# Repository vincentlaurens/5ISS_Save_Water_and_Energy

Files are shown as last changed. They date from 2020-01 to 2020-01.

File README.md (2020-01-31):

# Sensibilisation tool to save water and energy

Written by ILYA team

# Table of Contents
1. [Introduction](#introduction)
2. [TreeMap of the repository](#paragraph1)
3. [Architecture of the solution](#paragraph2)
4. [Device Layer](#paragraph3)
5. [Network Layer](#paragraph4)
6. [Application Layer](#paragraph5)
7. [VM](#paragraph7)
8. [Deployment](#paragraph8)

## Introduction 

Nowadays, people are becoming increasingly concerned about the future of our planet. The consequences of climate change are worse every year. Fighting against it has become a source of inspiration for many young entrepreneurs. ILYA is a young startup that is developing two products: a cyclic shower to reduce water consumption and an awareness tool to sensitive people to save water, energy and therefore money when taking a shower. In this report, we present in detail the second product, a tool that allows measuring in real-time the water and energy consumption during a shower. The prototype we developed consists of a sensor system that collects data on the water flow and quantity, stores it in a database, and then display an analysis of this data on a web interface.  The data is captured by an autonomous and energy-efficient node and is then sent via WiFi to a local server to be stored in a database and then on the cloud. The final prototype is not fully optimized but both simple and realistic.

## TreeMap of the repository 
```
Project ILYA
    |-README
    |-Documentation
    |   |-rapport.pdf
    |   |-Presentation.pdf
    |-DeviceLayer
    |   |-ESP_Code
    |-ApplicationLayer
    |   |-data_structure_api
    |   |-UI
    |-VM
    |   |-README
```

## Architecture of the solution 

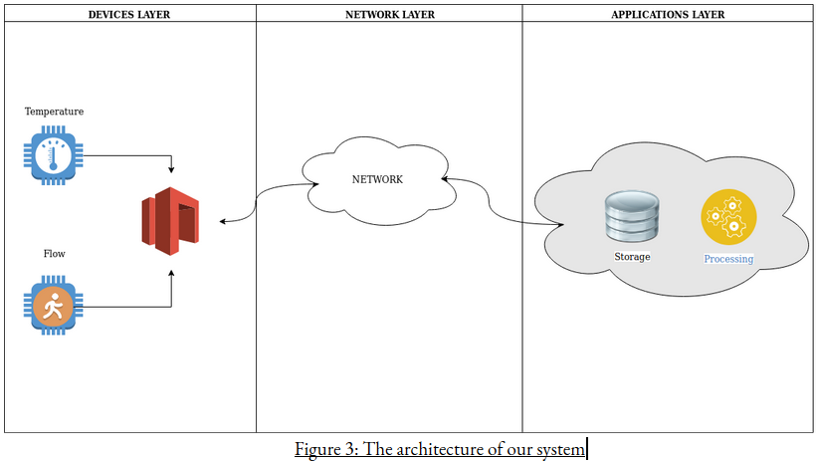
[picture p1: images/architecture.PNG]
Architecture


## Device Layer 

The Device layer is Composed of 4 different components for one module.
There are 2 sensors , 1 Microcontroller, 1 Shield.
This is the Bom of our Module:

|DEVICE NAME	 |Quantity |
| ---: | ---: |
|Grove - Temperature Sensor V1.2 | x1 |
|YFS-201 Hall Effect Water Flow Sensor | x1 |
|Node-MCU ESP8266	X1 | x1 |
|Grove Base Shield for NodeMCU | x1 |

The Arduino Code can retrieve data from sensors during a certain period : each 10 sec
Number of acquisition : 7 , Total time of acquisition : 70 sec.

This parameters are configurable in the source code which is commented to know the purposes of functions and variables
<a href="https://drive.google.com/file/d/1UWVMobrCpHeJf4AdiO7gw0xYP0oA8SGS/view?usp=sharing">Bill of Material (document)</a>

## Network Layer 

1.  Create an account on http://maqiatto.com
   Click on "CREATE ACCOUNT"
   Create your account
2.  After login, clic on your email address on the left top corner
   On the dropdown menu clic on "Broker configuration"
3.  Next page should appear
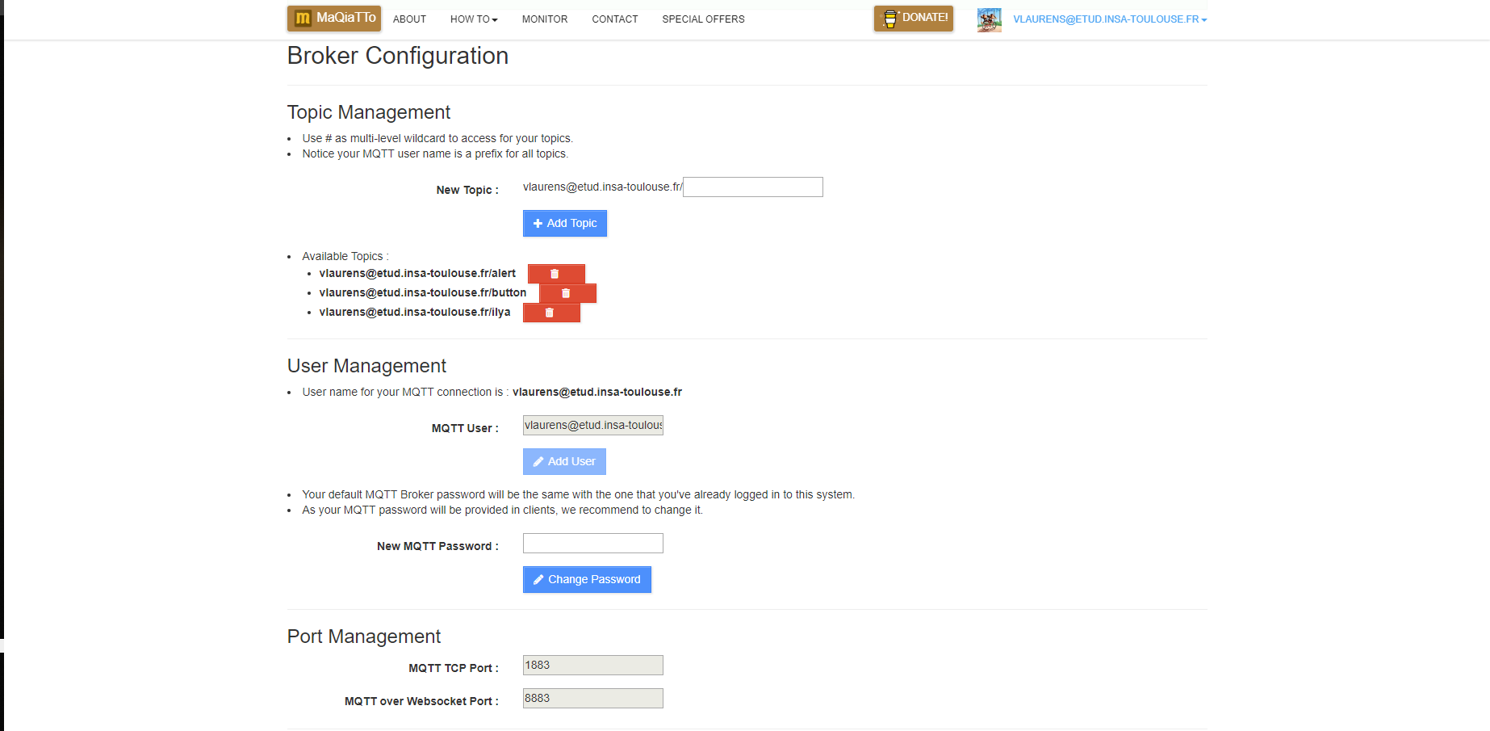
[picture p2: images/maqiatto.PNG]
Maqiatto broker configuration
    
    ADD the same topics as shown on the figure (cf First part :Device Layer where you have to replace created topic on the  global code variables)
4. Once differents topics are created you can monitor reception of JSON object by connecting to the http://www.hivemq.com/demos/websocket-client/ on a private window in your browser.
    Then you have to fill all the fields as shown in the next figure
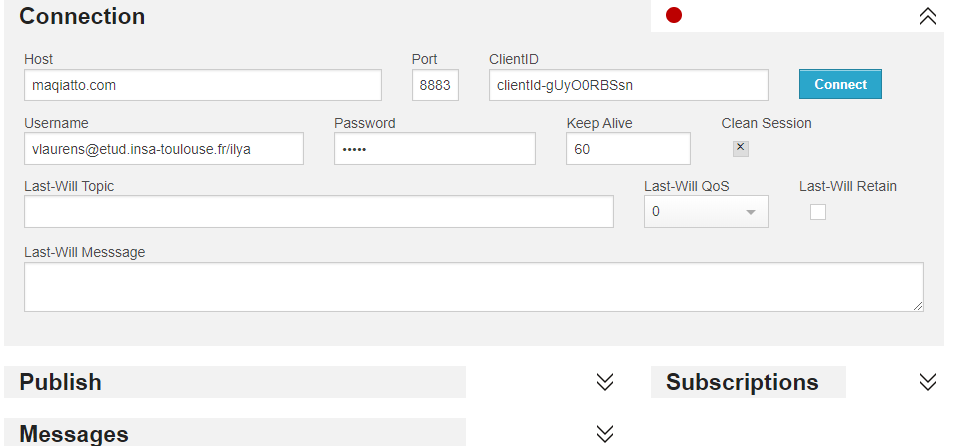
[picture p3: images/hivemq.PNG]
hivemq configuration
    
    Note that vlaurens@etud.insa-toulouse.fr/ilya is the main topic where all data are going to be sent. ( <maqiattoUsername>/ilya ingeneral).
 Ajouter image après  connexion

## Application Layer 

You can deploy the application either on a Ubuntu Virtual Machine or by deploying containers as describe in part 7 or on your computer if you have python installed but you will need to install some python modules using command and install mongo (https://docs.mongodb.com/manual/installation/) and for configuring data base mongodb-compass (https://www.mongodb.com/products/compass)
````
$  sudo apt-get update && apt-get install -y apt-utils && apt-get install -y python && apt-get install -y python-pip && pip install requests && pip install flask && pip install flask_restplus && pip install paho-mqtt && pip install pymongo
````
Then if you decide to install on your machine you have to install npm and nodejs (https://nodejs.org/fr/download/) to be able to install node-red and run the UI.

Then you will download the "ApplicationLayer/data_structure_api" folder from git repository

Move on the folder and run command:
````
$ python app.py
````

The API is ready to collect data from broker and store it on mongodb.

Then run 
````
$ node-red
````
Then open a browser and go on http://127.0.0.1:1880

If you can't show flows import the two flows which are on folder "ApplictionLayer/UI" as described on the following tutorial: https://nodered.org/docs/user-guide/editor/workspace/import-export.

  If some package are missing install "node-red-contrib-ui" via install menu of nodered.
  
    - Go on the same menu as import 
    - Choose "manage Palette"
    - Go on install package section
    - Search "node-red-contrib-ui" and install it
    - Exit and close "manage Palette" popup
    - Then Deploy Flow by clicking on "Deploy" Button.
    - Visit http://127.0.0.1:1880/ui
    
Then we present you a means to install a VM or the VM we prepare and do the same operation to deploy application on the VM.

We finally show how to deploy our application with containers docker instead of using VM. A better solution for a large scale deployment.

Notice : The VM can be deploy directly on a cloud platform.

## VM 
- Download the VM on the link : https://drive.google.com/drive/folders/14bD5Wj_I1dPEdrXSYJpSs-G7y7vcGLyr?usp=sharing
- Install VirtualBox and launch the VM. You can do like in this tutorial :<a href="https://www.vulgarisation-informatique.com/installer-virtualbox.php"> How to install VirtualBox and launch VM</a>
- Connect to the VM using  ilya/ilya then you have a document which explains every thing on the VM Desktop.
- Go on API folder
```bash 
  $ cd ~/Documents/API/data_structure_api/
  ```
 - Run the API like describe on Application Layer section:
 ````
$ python app.py
````
- Open a browser and enter http://127.0.0.1:1880/ui to show dashboards.
- If you can't access it:
- Run on a Terminal (ctrl+Alt+T) : node-red  command
 ```bash 
  $ node-red
  ```
- Then go on http://127.0.0.1:1880 you will see code of flows and then you can modify them or deploy them.
  You will find flows on 
  ```bash 
  $ cd ~/Documents/API/UI/
  ```
  If you can't show them import the two flows which are on folder "ApplictionLayer/UI" as described on the following tutorial: https://nodered.org/docs/user-guide/editor/workspace/import-export.
  If some package are missing install "node-red-contrib-ui" via install menu of nodered.
  
    - Go on the same menu as import 
    - Choose "manage Palette"
    - Go on install package section
    - Search "node-red-contrib-ui" and install it
    - Exit and close "manage Palette" popup
    - Then Deploy Flow by clicking on "Deploy" Button.
    - Visit http://127.0.0.1:1880/ui
  
  If you want to monitor DataBase you can open a terminal (you can use shortcut ctrl+Alt+T) enter the command : "mongodb-compass&"
  
- Then open a browser and see the interface. enter 127.0.0.1:27017 and press enter.
  You will see all the databases. The databases are created by the API at the first data reception.
  
  <a src="./VM/README.md">VM Documentation</a>
  
## How to deploy our services on cloud by barely method or using a host OS 

In folder "services" run following command to deploy services
```bash
$ docker-compose up -d
```
run following command to stop all services
```bash
$ docker-compose down
```

Then open 127.0.0.1:1880 and on the interface
select menu on the top-right corner
In the menu select "manage palette" and in install menu
Install node-red-dashboards

Then select import menu and import two json file which are located in folder ilyaUI directory

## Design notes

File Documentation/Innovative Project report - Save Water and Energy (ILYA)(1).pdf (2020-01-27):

## Innovative Project report

# Save Water and Energy

## Consumption awareness tool

INSA students

Karim Aldandachi
Mickaël Commerot
Vincent Laurens
Lorine Pose
Hamza Safri

ILYA founders

Simon Buoro
Antoine Escande

INSA Tutor

Thierry Monteil

## Acknowledgments

We would like to thank first of all Simon Buero and Antoine Estande, ILYA’s co-founders, for trusting us with their project and for giving us the opportunity to work on it.

We would like to also express our gratitude to our INSA tutor, Thierry Monteil, who accompanied us during this project, and we thank him for all the advice and help he provided us with.

We really appreciate the help given to us by Gauchard David, mainly on the ESP8266 development. His contribution was essential to the completion of this project.

Finally, we would like to thank our English teacher, Joseph Shea, for helping us with our written reports and oral presentations, and for always making sure our English is correct.

We dedicate the result of our hard work to our beloved classmate, Lorine Pose, who we know did the best she could to be a part of this project. We send her our best wishes.

2

## Abstract

Nowadays, people are becoming increasingly concerned about the future of our planet. The consequences of climate change are worse every year. Fighting against it has become a source of inspiration for many young entrepreneurs. ILYA isa young startup that is developing two products:a cyclic shower to reduce water consumption and an awareness tool to sensitive people to save water, energy and therefore money when taking a shower. In this report, we present in detail the second product, a tool that allows measuring in real-time the waterand energy consumption during ashower. The prototype we developed consists of a sensor system that collects data on the water flow and quantity, stores it in a database,and then display an analysis of this data on a web interface. The datais captured by an autonomous and energy-efficient node and is then sent via WiFi to alocal server to be stored in a database and then on the cloud. The final prototype is not fully optimized but both simple and realistic.

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
## I. Introduction

ILYA is a french start-up that aims to decrease the environmental impact of everyday actions by offering innovative and durable solutions to assist companies in their responsible approaches. Their first project is a sensibilization tool that provides an energy and water consumption diagnostic service to its clients.

Today, particularly in hotels, people tend to have an irresponsible consumption of water and energy. This phenomenon is mostly due to the fact that since they paid for the room, they feel the need to make the stay as profitable as possible.

To tackle this issue, ILYA wants to develop a solution that sensitizes people about their water and energy consumption in order to decrease it. This tool will be installed first in public places like hotels and camps, measuring the consumption, analyzing the collected data and then displaying it on a screen. Therefore, the person will be able to know how much he or she is consuming, while in the shower!

## II. State of Art

Before starting to design the prototype, we needed to research the tools and technologies we were going to use, mainly the circuit board and the type of database. Below is the result of our research.

A. Hardware

Before we started to design our prototype, we wrote down a list of requirements that the prototype had to respect. For example, it has to be autonomous and self-dependant on energy. In fact, the client will add that module in a bathroom and the system must beable to stand-alone foras long as possible. Therefore, we needed a module that is able to fetch data from sensors and to send them to a cloud using a Wi-Fi protocol, all while consuming the least amount of energy possible.

We chose to use ESP boards rather than other constructor boards like STM because we wanted a board that can connect to WiFi. Furthermore, the development kit proposed by ESP relies on Arduino’s development IDE (https://www.arduino.cc/en/Main/Software) , which is very easy to use. More importantly, ESP cards and Arduino
1
IDE had already been used by all team members in previous projects. For example, most team members used the ESP8266 board during INSA’s Hackathon back in December of last year.

1 https://www.arduino.cc/en/Main/Software

5

We narrowed the choices down to two ESP boards: ESP8266 and ESP32. The following paragraph will describe studies on the energy consumption of those two modules. In the first part, we will compare the energy consumption of ESP8266 and ESP32. In the second part, we will present the development environments used to develop the software of these boards.

To measure the energy consumption of both boards, we used a USB Safety Tester, which is a basic plug-in USB tester that displays voltage and current values.

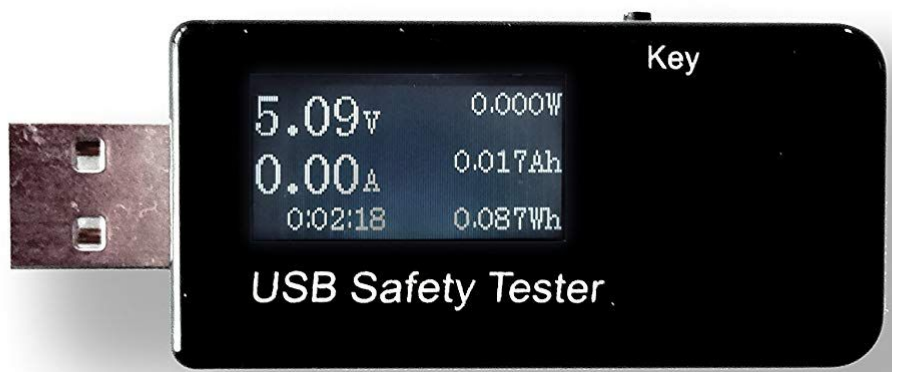
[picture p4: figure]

Figure 1: The USB Safety Tester

Below is a table presenting in more detail the different characteristics of each board.

| ESP32 | ESP8266
Microprocessor | Xtensa Dual-Core 32-bit LX6 with 600 DMIPS | Xtensa Single-core 32-bit L106
Number of cores | 2 | 1
Wi-Fi | Yes | Yes
Bluetooth | Yes | No
Supply needed in Run mode | 110 mA | 80 mA
Supply needed in Sleep mode | 50 mA | 20 mA
Energy consumption per min (I/P=UI/E=PI) Accuracy 1A | 110mA/0.05Watts/33 Joules | 80mA/0,04 Watts/24 Joules
Energy Management integrated | Yes | No

Table 1: Comparison between ESP32 and ESP8266 board

The results above show that an ESP8266 board consumes less energy than an ESP32 board with the same test conditions (program, temperature, sensors connected…). But if we look at the performance

6

aspect, an ESP32 board with two cores is more efficient than an ESP8266, which uses one core for Wi-Fi connection and transmission, and the other one to process data collection from sensors.

The development environment is something that must be taken into consideration because it is used to design the “brain” of the board. One thing that is important to mention is thatan ESP board hasa RISC microcontroller, which means that it can be programmed in C++ using Arduino IDE. This criterion is another reason, after the ability to connect to Wi-Fi, that comforted our choice ofan ESP board rather than an STM board.

In the end, we chose ESP8266. In fact, our system doesn’t necessarily need a high performing board because it will only collect and send data via Wi-Fi. The energy consumption criteria was a more critical point for our choice.

Complementary to the hardware part, we know that traditional groovesare very big so we had to think of a way to reduce the size, by having fewer inputs for example. We designed a PCB groove shield that is the size of the circuit board. It can be found in theappendix at the end of this document (Appendix 3).

B. Database

For our database, we had two options, SQL and NoSQL, the most common types of databases. We decided to compare them based on attributes like consistency, availability,and speed and then choose depending on the needs of our application.

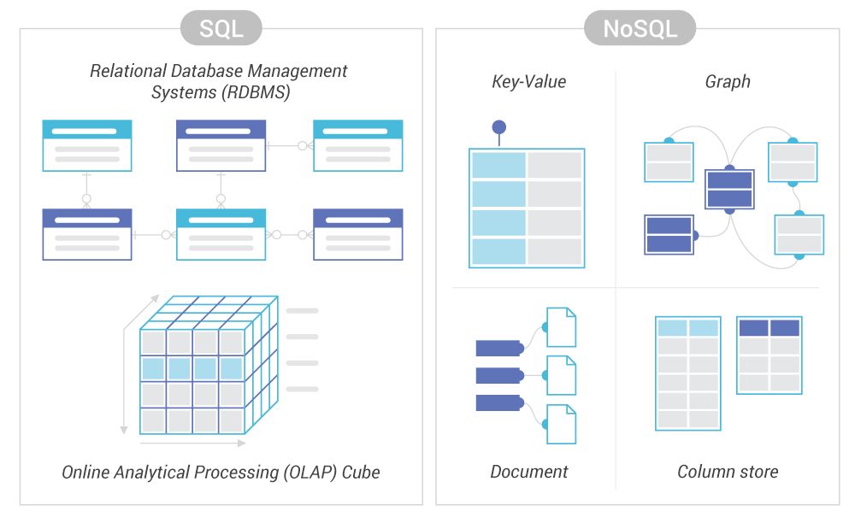
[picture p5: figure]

Figure 2: A representation of SQL and NoSQL databases

7

Source: https://www.scylladb.com/resources/nosql-vs-sql/

SQL stands for Structured Query Languageand is the traditionaland most popular database system. It is based on the relational model, which means that data is stored in interrelated tables, with rowsand columns. An indexing mechanism supported by SQL is used to speed up various operations like reading or creating views, which can join data from multiple tables. Examples of relational databases available are MySQL, Oracle, and SQLServer.

However, in the last couple of years, another database system has grown in popularity, due to its ease of access, speed, high scalability, and distributed computing. NoSQL is a non-relational database management system that supports flexible schema to store the data. NoSQL databases supportalarge scale of data storing by providing distributed data stores. Most of them are based on storing key-value pairs. Hence, they are suitable to store data generated by IoT applications. An example of a NoSQL database is MongoDB.

| SQL | NoSQL
Model | Relational database system | Non-relational database system
Data storage | Tables (rows and columns) | Documents, column stores, graphs, key-value pairs
Schema | Fixed, very hard to modify | Schema-free database, easy to modify
Data structure | Structured data | Semi-structured or unstructured data
New fields | Adding new fields in the table may require altering the schema | New fields can be added with much more ease
Scalability | Scales well vertically | More suited for horizontal scaling
Querying language | Use of powerful declarative language | Use of JSON data objects
Transactions | Supports ACID transactions | ACID transactions support varies per solution
Consistency | Strong | Eventual

8

Table 2: Comparison between SQL and NoSQL databases The following paragraphs are based on the paper written by Rautmare, S. and Bhalerao, D.

- Data model:
SQL is a relational database where data is stored in the form of rows and columns in tables that are linked together. In the table, columns represent different fields, while rows represent the records. This data model gives a well organized but rigid structure of data. For example, the same table cannot be used to store different kinds of information. You also can’t inserta number whereastring is expected. This strict data template enables a low probability of a user making mistakes.

On the other hand, NoSQL is a non-relational database that uses data modeling types like document stores, key-values, and graphs. Similar documents can be stored in a collection, which is analogous to an SQL table. You can store any type of datain any document. This flexibility can lead to consistency issues. Nonetheless, this feature proves to be efficient when handling unstructured data like Word, PDF or multimedia files.

In IoT applications where data structure cannot be predefined properly or data is heterogeneous, NoSQL definitely has a higher edge. But for simplerapplications,afixed datastructure is enough and accessing data is faster.

- Scalability:
Vertical scalability is the ability to scale up or to add resources to a single node in a system, typically involving the addition of CPUs or memories to a single computer. Traditional databases like SQL were designed primarily to scale vertically by adding more power to a single node. Horizontal scalability is the ability to scale out or to add more nodes (servers) to the system so its load can be shared. It is one of the main characteristics of NoSQL.

For IoT applications where the distribution of data amongst several servers is required, the use of NoSQL isa better option because itallows the expansion of the hardware system in astepwise manner, without needing to invest in high-end modules of hardware.

- Data Retrieval:
To look up data in SQL databases, the user needs to collect it from interlinked tables using JOIN statements and then combine the results. The process is the same when writing.

In NoSQL, each piece of data represents an object which contains all its related data. This allows a much faster Read and Write operations. This feature is mainly required when analyzing the datastored in the database or when taking any action on a specific record.

9

- Transactions:
Relational databases like SQL support ACID (Atomicity, Consistency, Isolation, Durability) properties and hence guarantee the validity of all transactions. NoSQL supports BASE (Basically Available, Soft state, Eventual consistency) properties, focusing more on eventual consistency, providing availability and on being partition tolerant.

For IoT applications in their developing stage, data generation increases day by day. So, a database system that is partition tolerant is more suitable. Also, in IoT applications where datais collected first and then analyzed, later on, the database can be eventually consistent. In this case, strong consistency is not a mandatory characteristic. It is better suited in application scenarios where an immediate update of data is necessary (online reservation systems, inventory systems, retail stores, banking).

- Maturity of the system:
Finally, one of the most important issues in a database is security. As NoSQL is a recent technology and hence is less mature, it is more likely to generate new issues, due to alack of knowledge. Developers have less experience with newer database systems, so mistakes are made. On the other hand, in SQL, most of the issues are all addressed as it has been used for several years now. Security concerns like authentication, data integrity, confidentiality, auditing, and client communication are addressed in SQL. In NoSQL, they are yet to be integrated.

In the IoT ecosystem, sensors transfer a lot of sensitive information. So, it is necessary to haveasecure channel for information exchange and a secure system to store this sensitive data. For applications where data security and integrity is of high priority, it is better to go for a secured data storage like SQL.

After studying all these different attributes, we opted for a NoSQL database because its structure is more suited to the evolving data schemas of our project.

## III. The implementation

a) A general overview of the tool

The tool consists of sensors, a circuit board, and a cloud. The sensors are placed on the showerhead and measure the temperature as well as the water flow. The circuit board then receives the data and sends it to the cloud, where a database is stored.

Each sensor is linked to a specific hotel room when configured. In fact, we need to beable to attribute each data to the corresponding shower head.

10 b) The architecture of the tool

To design our tool’s architecture, we got the inspiration from the M2M standard developed by the European Telecommunication Standard Institute (ETSI), which is used in many markets, such as Connected Vehicles, Smart Metering, and e-Health.

ETSI identifies three domains: Application, Network, and Device. The Device layer consists of sensors, actuators, and any other type of device found in a wireless sensor network. It also contains a gateway to be used by devices that can’t connect by themselves to the M2M core. The Application layer, as its name suggests, contains all the differentapplications. Finally, the Network layer providesa communication network between the Application and the Device domains. [1]

For our specific tool, here is how we designed the architecture:

- The device layer contains the different sensors (flow and temperature) which are connected to an ESP8266 circuit board. These sensors send the collected data using the Wi-Fi module of the board to a broker, which in turn sends them to M2M applications.
- The network layer is responsible for the communication between the circuit board and the database. This is done thanks to a broker. A broker is something or someone that acts as an intermediary third party, managing transactions between two other entities. In the case of our tool, the broker is an intermediary computer program module that publishesa message forall subscribed applications.
- The application layer provides 2 services. The first consists of a MongoDB database that receives and stores the collected data. The second isan interface used by the supplier (Ilya)and the clients (hotel managers) to configure sensorsand visualize the collected datain the form of graphs.

11

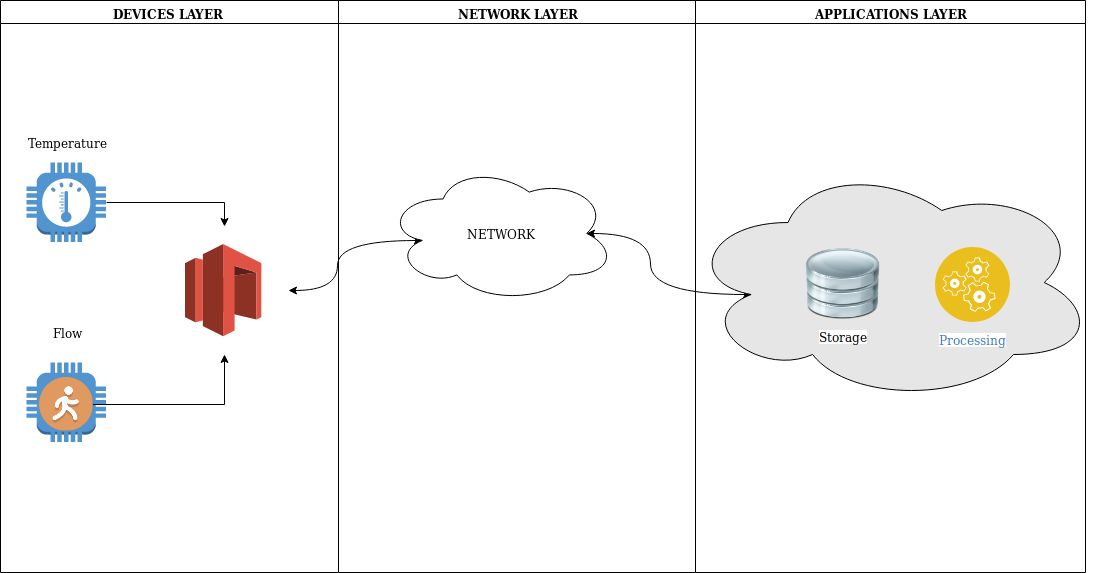
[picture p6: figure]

Figure 3: The architecture of our system

c) The Device Layer

In the Hardware state of the art, we explained the thought process that led us to choose an ESP8266 circuit board instead of an ESP32 or any board sold by STM (less energy consumption, Wi-Fi module available). Regarding the sensors, we needed them to give us information on the water flow as wellas its temperature. Therefore, we used two types of sensors: a temperature sensor and a flow sensor.

For the temperature sensor, we used one called The Grove. It detects theambient temperature thanks to a thermistor whose resistance increases when the temperature decreases. It can detect any temperature ranging from -40° to 125° with an accuracy of +/- 1,5°.

12

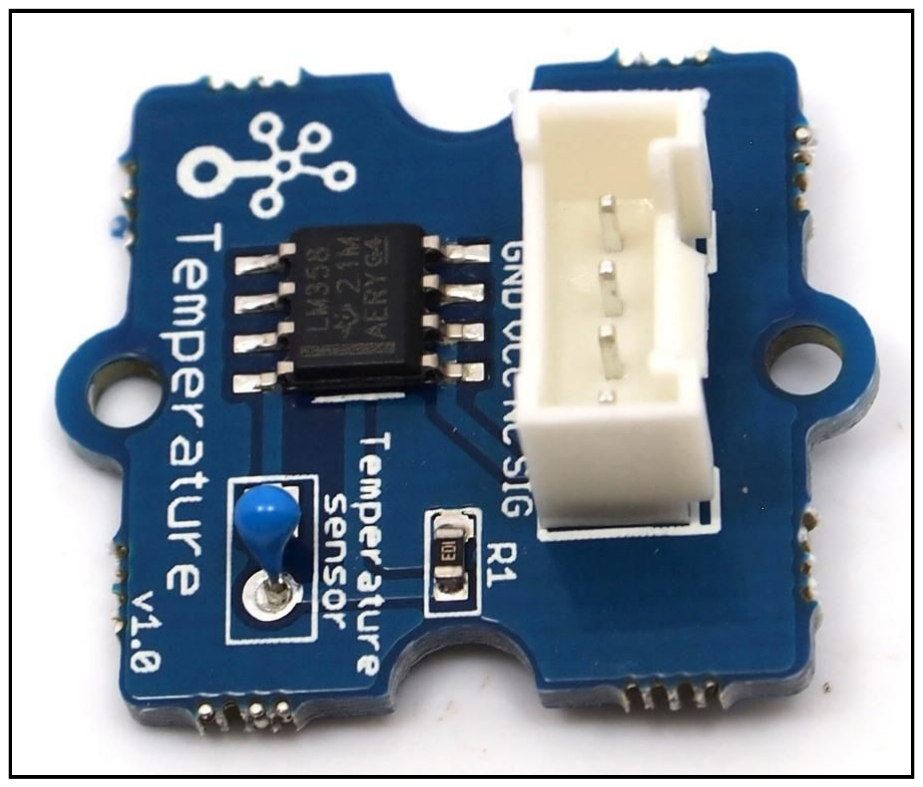
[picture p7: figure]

Figure 4: The Grove temperature sensor

As for the flow sensor, we used a YSF 201 Hall Effect Water Flow Meter. It containsa pinwheel sensor to measure how much liquid has moved through it. An integrated magnetic hall effect sensor outputs an electrical pulse with every revolution of the wheel. The water flow can be deduced from the frequency of the generated output signal.

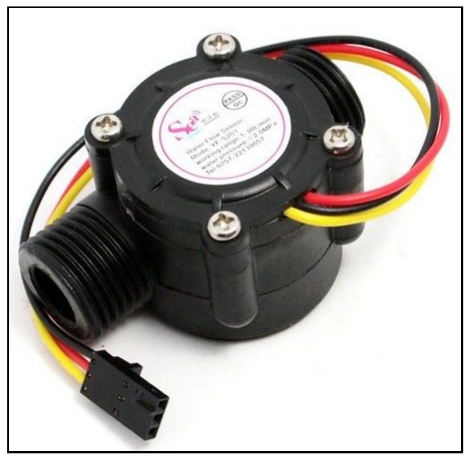
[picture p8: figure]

Figure 5: The YSF 201 sensor

d) The Network layer

The Network layer is the interface between the Device layer and the Application layer, enabling the communication between them. On one hand, the monitoring application must beable to get the data from the sensors. On the other hand, the application server must be able to receive a request containing data sensors inside the payload. To send a request, there are many different network protocols to choose from.

13

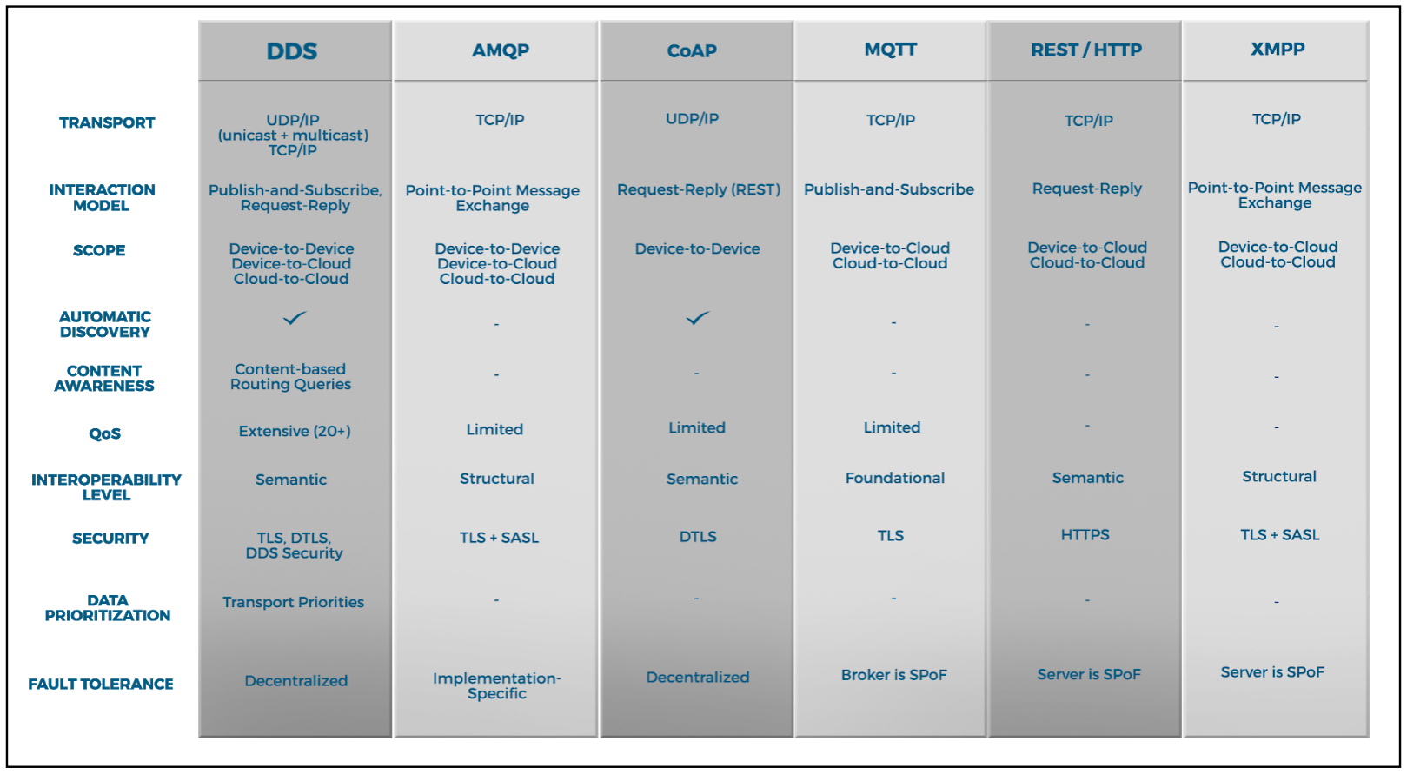
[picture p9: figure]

Figure 6: A comparison of the different existing network protocols Source: https://istblog.adlinktech.com/tag/messaging-protocol/

14

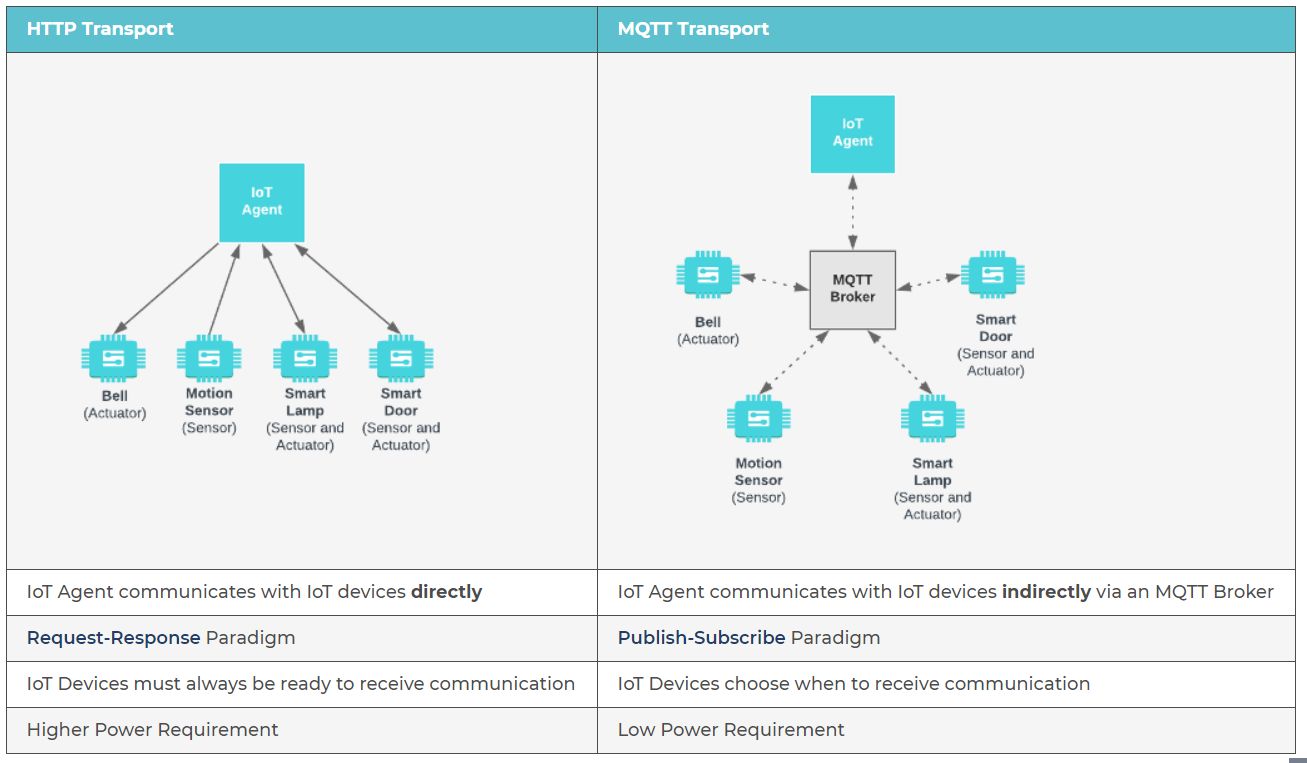
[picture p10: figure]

Figure 7: A visual comparison between HTTP and MQTT Source: https://fiware-tutorials.readthedocs.io/en/latest/iot-over-mqtt/index.html

In the context of IoT, 3 main protocols can be used: CoAP, MQTT or HTTP.

- CoAP is based on the UDP protocol, which means that it sends data without getting feedback once the receiver has received the message. Therefore, data can get lost.
- HTTP is based on the TCP/IP protocol, which means that it gets a feedback message when the message is received. This requires more energy.
- MQTT uses a server broker which is the intermediate between the two ends. Thereare fewer requests and thus less energy consumption.

With this comparison, we can easily see that MQTT is the best solution for our tool. In fact, we cannot afford to lose information from the sensors (that would alter theanalysis),and the low energy consumption, as we mentioned before, is a very important criterion.

For the initial testing phase, we only needed an already existing MQTT broker. After researching fora free and online MQTT broker, we found one called MaQiaTTo. It was interesting for us to use it because it hosts an online MQTT broker and allows us to easily create topics. However, there was a

15 slight disadvantage of limiting the number of users to only one. Nonetheless, we still decided to use it for our tests because it is available everywhere, as long as there is an Internet connection.

Once we validated the tests, we needed to have a private MQTT broker for Ilya, instead of relying on an online version. So, we implemented our own Mosquitto broker and hosted it on a virtual machine (VM). Mosquitto isan open-source, configurableand fully implementable MQTT broker. Not only it doesn’t limit the number of users like MaQiqTTo, but itallows theadministrator to define the ACLs (Access Control List) for each user. That way,a user will only beable to publish on topics where he or she has the right to. This translates into extra security to protect each hotel’s data. However, it is less transportable during tests because it requires the VM to be connected through the web, which is why we had to use MaQiaTTo first for the tests.

e) The Application layer
i) Data structure

The data structure is an essential phase in the age of data. As mentioned before, we used a NoSQL database. In this project, we can classify the data into two groups:

- Indexing data: an ID field created by Ilya to identify a device in a hotel
- Collected data: the data sent by the device to the database via the broker

Therefore, we created two databases. The first one isan indexing database that contains mapping data between the device id and the path to the database storing the collected data. The second one stores the data collected from the shower sensors. In order to properly structure the data, we programmed a Rest service that plays the role of an intermediary between the broker and the database, as wellas between the database and the web interface.

16

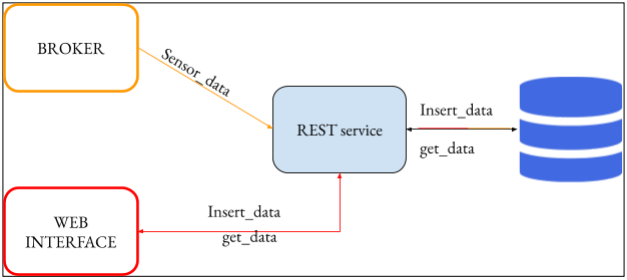
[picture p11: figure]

Figure 8: The architecture of the REST service

ii) Web interface

The interface’s purpose is to visualize the data given by the sensorsand to plot chartsand dashboards. We used Node-RED, a programming tool that enables us to wire together hardware devices, APIsand online services, using a wide range of nodes. It is very practical to use because it is a browser-based editor, which means that it can be run on any operating system without too many dependencies. The tool offers as well a code interface that is directly integrated into the browser. Furthermore, a deep knowledge of programming languages and algorithms isn’t necessary to build an application on it.

17

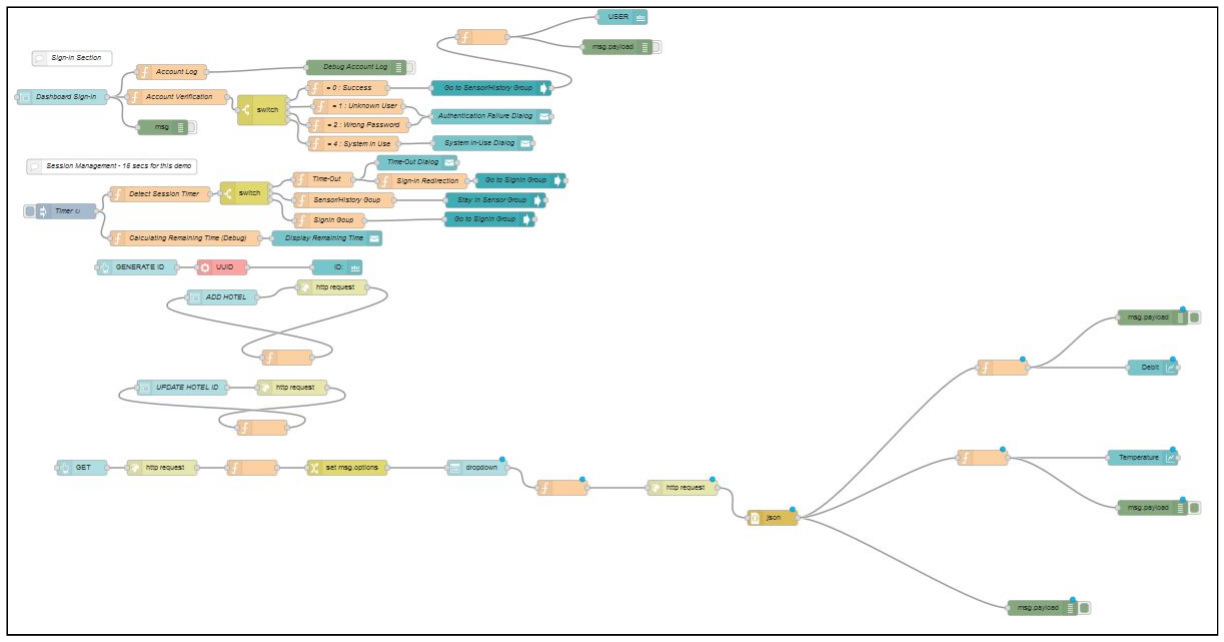
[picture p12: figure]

Figure 9: A visual of our application services on Node-RED

In our scenario, we divided the interface into two parts. The first is a service that allows the user (ILYA) to select and retrieve data from the database, as well as print charts and statistics on a dashboard. The second part is for the configuration of sensors. The user can generatea unique id fora newly-installed sensor, add it to the corresponding hotel or update the sensor’s id.

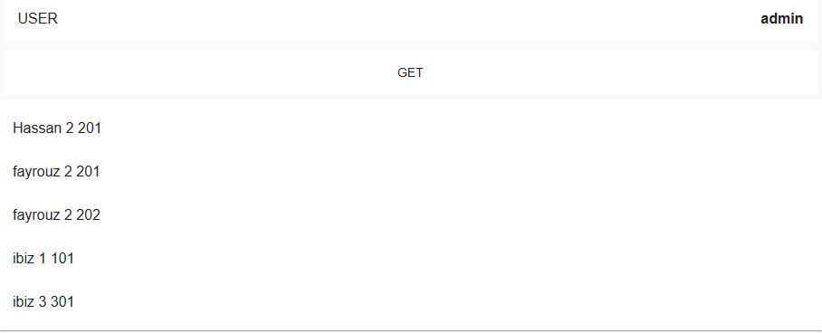
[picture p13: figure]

Figure 10: The first service of the interface

In the picture above, the administrator can retrieve data from sensors situated in room 201 in Hassan hotel, rooms 201 and 202 on the second floor of Fayrouz hotel and rooms 101 and 301 in Ibis hotel.

18

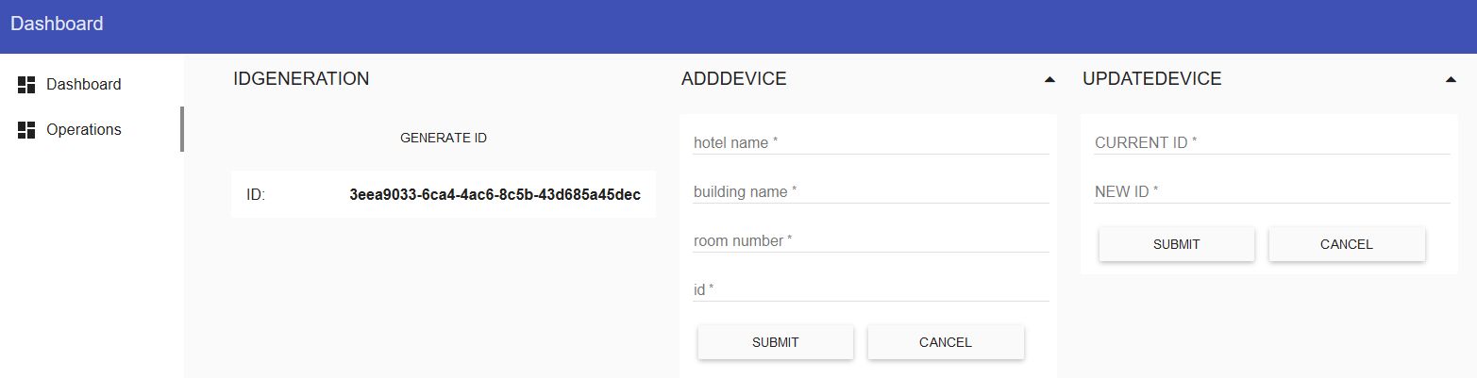
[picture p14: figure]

Figure 11: The second service of the interface

In the picture above, the user has generated a new id (3eea9033-6ca4-4ac6-8c5b-43d685a45dec) for a sensor using the ‘IDGENERATION” button. This id is then used when configuring the new sensor in a specific hotel room.

f) The final implementation

At the end of the project, we packed our prototype to make sure that it is functioning well. We also wanted a turnkey solution. So, we gathered all the application layer entities (Web interface and Data structure) on a single virtual machine. The objective is to have an application layer that can be easily deployed on a cloud provider, but also to be able to deploy and use it without having to install anything (an OS or a hypervisor).

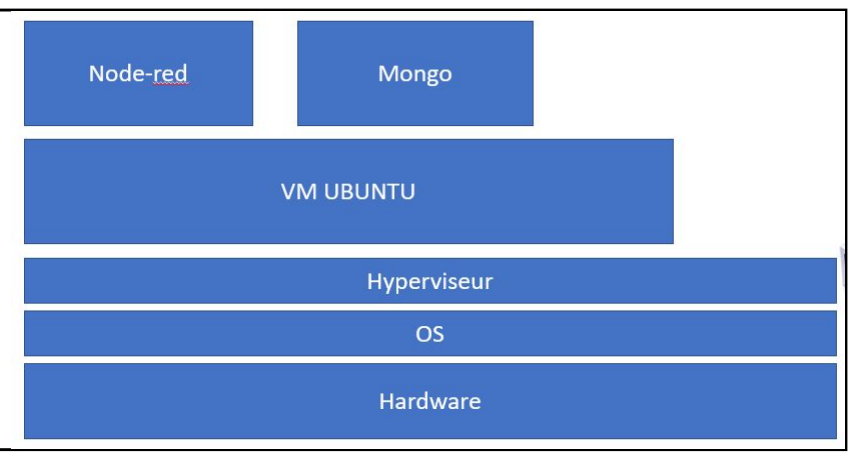
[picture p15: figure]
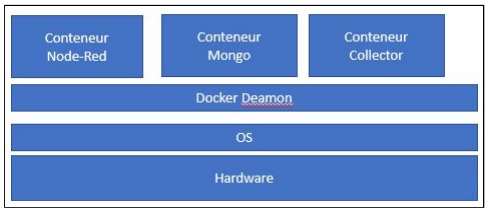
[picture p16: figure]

Figure 12: Description of virtualization (POC package on the left, industrialization version on the right)

On the figures above, we can observe that the first solution we proposed consisted of deploying services on a virtual machine (VM). It that case, the VM containing all services (database, UI, collector python) can be deployed on any cloud (OpenStack, Azure, AWS, Google…). Indeed, we want our application to be deployed without any complementary configuration.

19

Once we finalized our VM, we started to imagine a solution that would be more scalable, based on containerization. Indeed, we know that using containers allows the solution to be serverless which helps to scale the application’s storage capacity up or down depending on the demand. The more requests there are from clients, the more we will deploy container instances to load and balance the demand, instead of overloading the servers. Anotheradvantage of using containers rather than a VM is the fact that containers can be installed very fast.

To implement our VM, we used an Ubuntu distribution where we installed Node-Red (npm, nodejs), git, python3, and MongoDB. That way, to start the services, we just needed to start the VM. Once we validated the implementation of the VM, we implemented a container solution based on DOCKER technology. We prepared this solution to introduce our services in an industrial environment. From a technical aspect, containers can be directly started on a cloud (OpenStack, AWS, Azure, etc.) using a recipe we wrote in a DockerFile stored on the “serviceDocker” branch.

## IV. Project management

a) Team members

Our team is composed of five INSA students from varying academic backgrounds.

- Karim Aldandachi: specialized in Embedded Systems, double degree program at TSM in International Management.
- Mickaël Commérot: specialized in Computer Science, Master REOC (Réseaux Embarqués, Objets Connectés) at INP.
- Vincent Laurens: computer branch, specialized in Networks and Telecommunication.
- Lorine Pose: specialized in Embedded Systems.
- Hamza Safri: specialized in Computing, Networks, and Telecommunication, Master REOC (Réseaux Embarqués, Objets Connectés) at INP.

The variety of academic backgrounds amongst team members was a good thing because itallowed us to learn from each other’s way of working and knowledge. This also helped us to cover all aspects of the project (Networking, database, electronics, team management…).

b) The organization of our team

We chose to undergo this project using the Agile method. First, we divided the overall project into different sub-projects and tasks and assigned each one to a team member. We also divided it into different sprints that lasted 3 weeks each. We agreed to meet once every week to keep each other in

20 touch with the latest developmentsand difficulties. Wealso tried to meet the client every week to keep them updated on our progress. But that wasn’t always possible because of scheduling issues.

We knew right from the start that this wasn’t like any of our previous projects done at INSA. It was bigger, more demanding and the stakes were higher. Therefore, we decided to search forasoftware or website that would allow us to better manage the team as wellas the project,and most importantly to keep track of our progress throughout the weeks. The software we chose is a task management app called Trello. It is used by millions of people and organizations all around the world to manage and organize projects. What’s good about it is that it givesa visual overview of what is being worked on and who is working on it. This fits our decision to assign tasks to each member, as mentioned above.

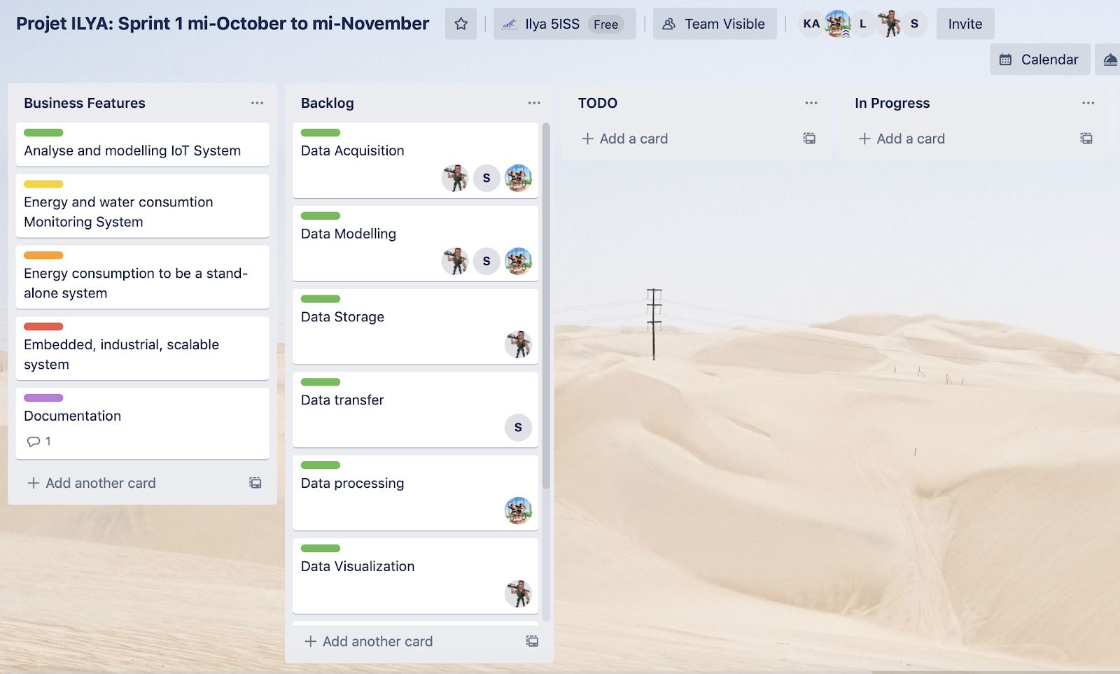
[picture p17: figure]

Figure 13: Our first sprint detailed on Trello

c) Difficulties faced

The main difficulty our team had to face was setting up a meeting with each other, as well as with ILYA’s founders. Indeed, as mentioned above, weall had varying backgrounds, with some in a double degree program or in professional training. Therefore, we all had different and heavy schedules. Finding a timeslot that suited everyone’s schedule was challenging every time we needed to meet. As one would expect, not everyone was able to come to every meeting. But to solve this issue, someone

21 simply took care of taking notes and then wrote a report that was later sent to every team member. This not only allowed any absentee to keep track of what was discussed,and therefore not miss out on any new developments but also to keep a record of what was said exactly.

Another difficulty was the fact that one of our members, Lorine, left the project mid-way for personal reasons. Therefore, we had to re-assign her part of the project between us, on top of what we each already had to do. This was definitely unexpected and it provoked a slight moment of panic in the team. We also had to adjust the sprints and the corresponding deadlines.

Another challenge was finding a balance between working on this project and still meeting all the other deadlines we had for other subjects, the extra double-degree work for some of us and the professional training for others. This wasn’t an easy task.

22

## V. Conclusion

At the beginning of this year when we wereassigned to this project, we saw an opportunity to use our years of learning and technical experience to develop an innovative solution that would help the planet. The requirements for this project were the following: provideafunctioning Proof of Concept of the tool, with the Network communication, sensor data, database management,and visual interface all taken care of. ILYA expected to have a functioning prototype where we can connect sensors they have designed and which are able to retrieve values and store them on a database.

We are happy to say that we successfully met the challenge. Throughout this report, we have presented the findings from our preliminary research to explain why we chose an ESP8266 circuit board and a MongoDB database system. We have also described how we designed the architecture of the tooland then went into more detail for each of its layers. We followed that up with an evaluation of the way we handled the project and the difficulties we faced.

However, we weren’t able to tackle the energy consumption of the tool very well, due to a lack of knowledge as well as a lack of time. The founders wished to use BLE but we used Wi-Fi.

23

## Bibliography/Webography

[1] A Feasibility Study on Developing IoT/M2M Applications over ETSI M2M Architecture
[2] Expressif, Datasheet of ESP8266 (2018). [online] Available at: https://www.google.com/url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 w0teH8Qd8wMW9ICXxdEvzq- (https://espressif.com/sites/default/files/documentation/0a-esp8266ex_datasheet_en.pdf)
[3] Expressif, Datasheet of ESP32 (2019), [online] Available at : https://www.espressif.com/sites/default/files/documentation/esp32-wroom-32_datasheet_en.pdf
[4] Docker website, [online] Available at :
https://www.docker.com

Rautmare, S. and Bhalerao, D. (2016). SQL & NoSQL Database Study for Internet of Things. [online] Available at: http://www.ijirset.com/upload/2016/may/350_Sharvari%20Paper.pdf [Accessed 12 Jan. 2020].

24

## Appendix

1) Requirements document

# Requirements document

### Sensibilization Tool

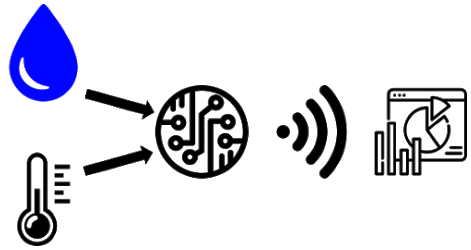
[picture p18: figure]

Prepared by: ILYA Team
Prepared for: ILYA founders Date Submitted: Nov 07, 2019

Project Sponsor: Thierry Monteil
Client Acceptor: | ILYA
Project Manager: | Vincent Laurens
Team members: Mickaël Comerot, Hamza Safri, Lorine Pose, Karim Aldandachi

Document Number: 1111-11/Project Number /BRD
Security Classification: Low
Version: 0.1

Creation Date: Nov 07, 2019
Last Updated: Nov 07, 2019

25

Project Overview | 2
Statement of functionality | 3
Expected Results | 3
Performance requirement | 4
Usability requirements | 4
Out of Scope | 4

26

Project Overview

The main idea of the project is to provide an Energy and Water consumption diagnostic service to clients. Today, particularly in hotels, people tend to have an irresponsible consumption of water and energy. This phenomenon is probably due to the fact that since they paid for the room, they need to make the stay as profitable as possible.

ILYA is a company that proposes innovative and durable solutions in order to decrease the environmental impact of everyday actions and to assist companies in their responsible approaches.

In this case, the purpose of the project is to sensitize people in order to decrease their water consumption at first in public places such as hotels. To do so, the company is looking for a tool that can be used to do consumption measurements for several weeks and then to analyze the collected data.

A sensors system collector in the Device layer will be added to the client's bathroom appliances (shower, sink, toilet…). This collector is equipped with aflow and temperature sensor that collects data and sends it to a gateway connected to the cloud, which will then store it in a database hosted on the cloud.

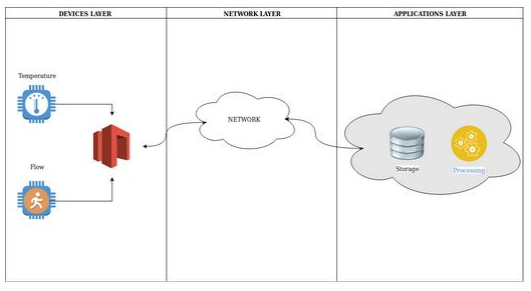
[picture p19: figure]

Figure 1: Architecture design overview

An application layer will be needed to establish statistics on data valuesand print resulted in charts of flow, volume of water, shower temperature, and energy consumption analysis.

Statement of functionality

An electronic acquisition system will be able to fetch the temperatureand debit sensors' values. Then, it will model the data and store it in a database hosted on the cloud. This software will allow users to have a real-time look on their energy and water consumption when they haveashower, just by using a

27 web application. The web interface has a Statistics dashboard of the flow, time and heat for each shower or sink in the bathroom.

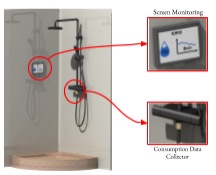
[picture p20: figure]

Figure 2: Sensors on a shower head It also needs an Administrator access for the service providers, a Configuration access for the people who will install the sensors, an unmodifiable access to the data for the clients, and eventually a real-time display of the information for the users (the clients of the clients), as shown in the figure above.

Expected Results

❏ A functional Proof of Concept with flow and temperature sensors;
❏ A database with tools to display the data on dashboards;
❏ Documentation about the work done in order for the project to be continued later on.

Performance requirements

- We want the user to access statistics in real-time on a dashboard.
- We have to fix a data loss tolerance to 20% during transfer from sensor to cloud data storage. Usability requirements
- The system must be easy to deploy or to use in a bathroom.
- Users must have an easy access to data via a user-friendly dashboard web application.
- Users can log in on an interface with their credentials, and then have access to the statistics.
- Users shouldn’t be able to modify the configuration of the dashboard.
- Users can change the Installation and Deployment configurations, via an Administration view.

28

Out of Scope

We don’t take into consideration neither the “Network Layer” issues described in Figure 1, the Industrialization process, nor the Integration process.

29

2) Poster

This poster summarizes the scope of this project and the solution.

30

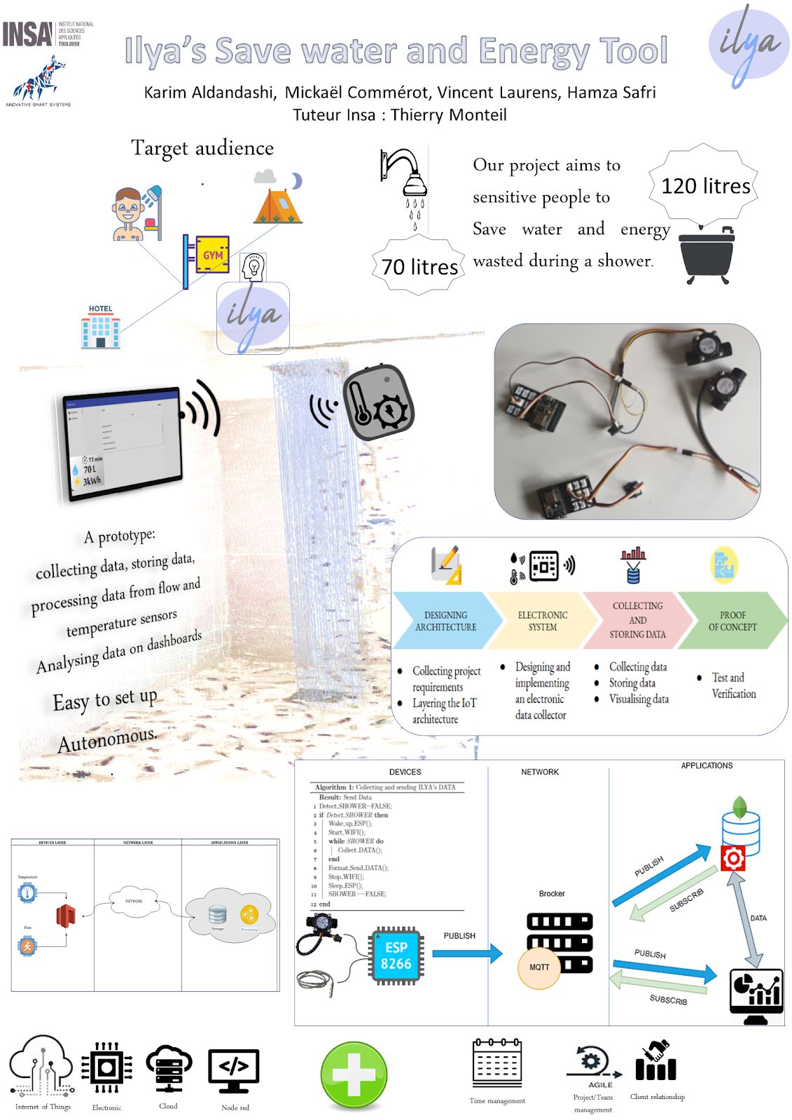
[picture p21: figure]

3) PCB groove shield design

While working on this project, we faced a crucial problem of space because our prototypeas of now is not minimised. So, we thought about a solution which can be improved to start reducing the size. We designed a PCB groove which containsa connector for bot sensorsand another one for power supply. In this document, we will describe the design of our shield.

We used a software called Kicad. It links several design tools together: EESCHEMA to design an electronic circuit and verify if the fundamental electric rulesare respected, PCBnew to design the PCB component form, the final shape of the board and to make routing connexion of components by defining tracks.

The first step was to design the electronic components and the connections between them.

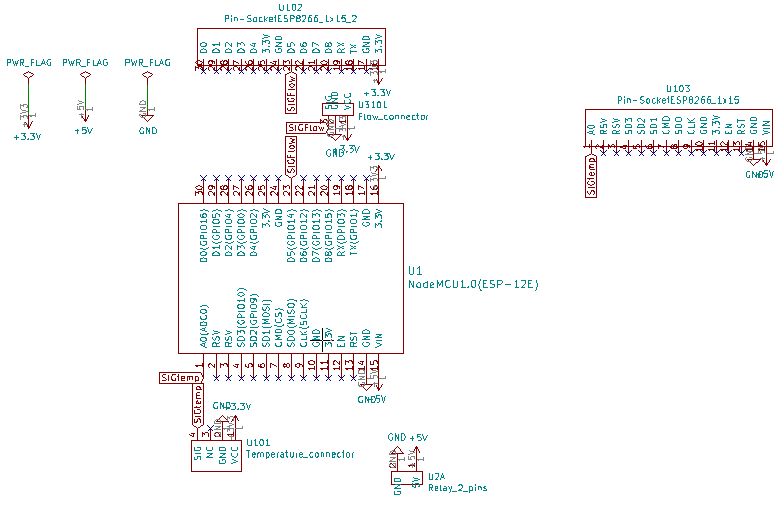
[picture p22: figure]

Figure 1: Schema of the PCB

Once that was done, the next step consisted in designing the PCB footprints of components. We routed all the tracks to connect components on the board, following Kicad design rules. For example, the size of the tracks had to match the numbers shown on the table below.

31

Furthermore, all the routing had to be concentrated on the same copper layer so that the PCB is easier and cheaper to make. To limit the track number on the board, we defined the board as the ground plan to connect all ground pads, i.e a copper layer which allows a component to be connected on the board.

On the figure below, we can see on the left, the routing schemaand on the right, the routing showing the current and impact of the ground plan.

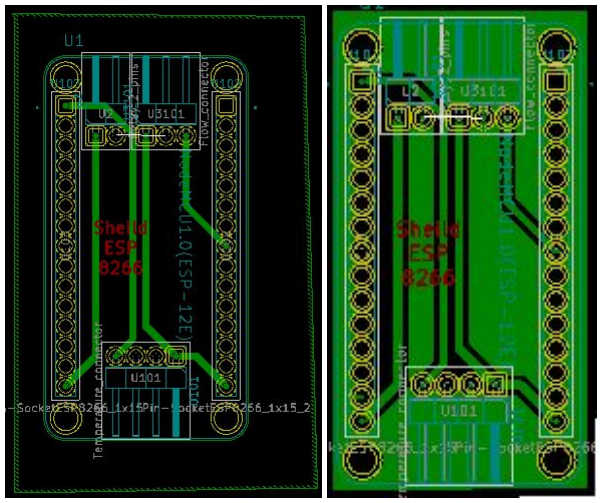
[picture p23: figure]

Figure 2: Description of the PCB routing

As a conclusion, here is a 3D view of the board. The Kicad project can be accessed on the “PCB” branch of our repository.

32

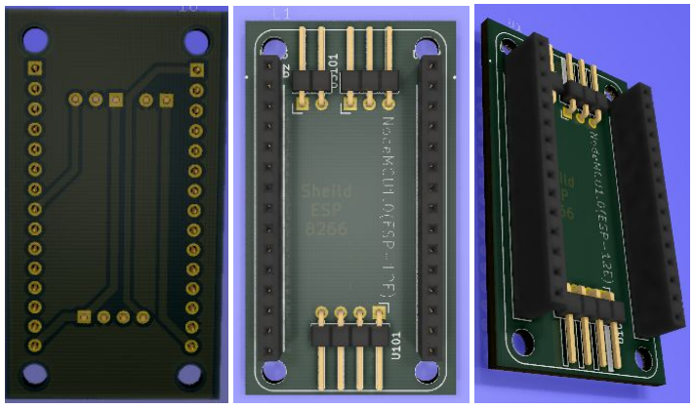
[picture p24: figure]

Figure 3: 3D view of the PCB groove

33

4) Abstracts

Abstract of Vincent Laurens

Lately, people have become increasingly concerned about the future of our planet. Ilya is a young company that is looking to develop two products that aim to save money and raise awareness about their water consumption mainly when they take a shower. We will present in detail atool thatallows people to measure the waterand energy consumption ofashower in real time. We presenta prototype based on a sensor system collecting data on water flow and quantity and storing it in a database in order to display it on a web interface. The data is captured by a node that must be autonomous and energy efficient. Data collected are then sent via Bluetooth Low Energy protocol to alocal server to be stored in a database and then stored on the cloud. We expect to create a prototype that is not fully optimized but both simple and realistic that collects data in the shower and displays it on a web interface.

Abstract of Hamza Safri

Energy and water are intricately connected. This connection is obvious when using heated water for showers, washing hands, or doing the laundry. However, cold water also costs great energy consumption. In order to reduce risks associated with disruptions in water and energy, or increase of its cost, those elements should be monitored. This project presents a design of a low cost system for near real time monitoring of the water and energy using the potential of IoT (Internet of Things). The system has in one hand several sensors used to measure the water's Temperature and energy. On the other hand, it has a web interface to visualise the sensor data stored in a database.

Abstract of Mickaël Commérot

Nowadays, environmental issues are increasing more and more. The new trend is to recycleand reuse resources in order to avoid too much waste. Moreover, people tend to have an irresponsible use of water during showers especially in hotels or gyms. ILYA isastartup thataims to contribute to finding a solution to this environmental challenge. They propose an IoT solution that reduces energy and water consumption during a shower. The solution consists in measuring the water flow and temperature thanks to a connected device, and then in sending the collected data to an online application. This report presents this energy monitoring system, from its conception to its implementation and design.

Abstract of Karim Aldandachi

34

The effects of climate are more catastrophic every year. Fighting against it has become a common cause for all governments, organisations and populations. Companies

35

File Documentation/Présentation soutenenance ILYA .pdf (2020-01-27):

## Save Water and Energy

## Consumption Awareness Tool

January 23, 2020

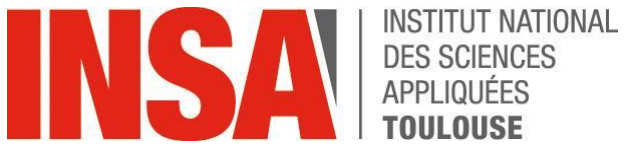
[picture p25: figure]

INSA students
Karim Aldandachi
Mickaël Commerot
Vincent Laurens
Lorine Pose
Hamza Safri

ILYA founders
Simon Buoro
Antoine Escande

INSA Tutor
Thierry Monteil

# I. Overview II. The IoT architecture III. The solution packaging IV. Project Management V. Conclusion

# Outline

# I. Overview

### A. The context B. The team C. The solution: an awareness tool

# II. The IoT architecture III. The solution packaging IV. Project Management V. Conclusion

# The context

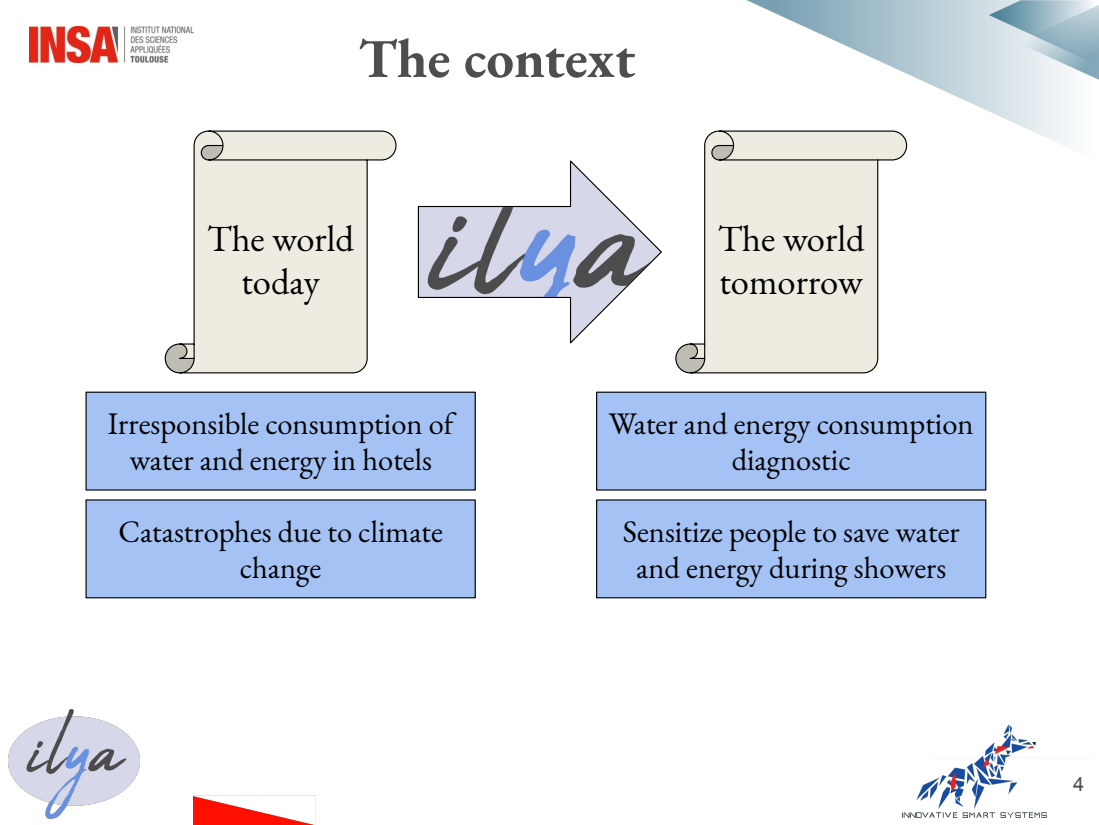
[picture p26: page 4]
change; The world today; The world tomorrow

Irresponsible consumption of
water and energy in hotels
Catastrophes due to climate

Water and energy consumption

diagnostic
Sensitize people to save water
and energy during showers

# The team

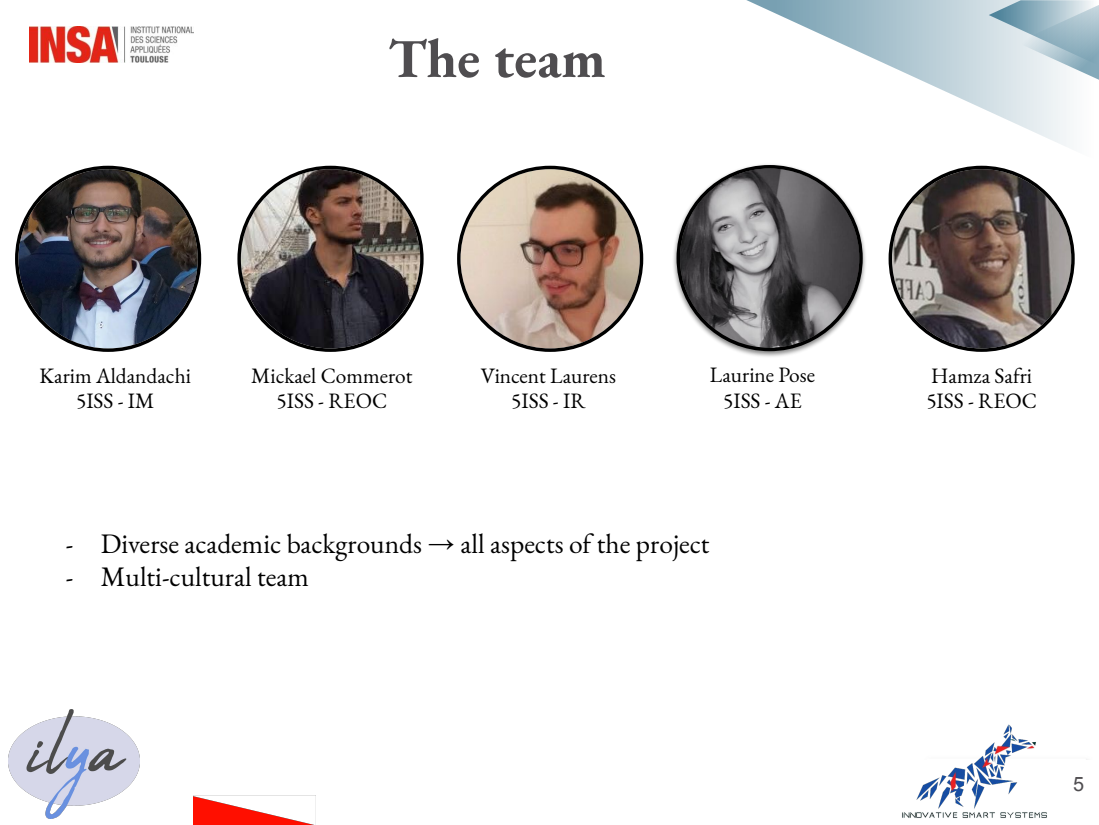
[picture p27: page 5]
Karim Aldandachi 5ISS - IM; Mickael Commerot 5ISS - REOC; Hamza Safri 5ISS - REOC; Laurine Pose 5ISS - AE; Vincent Laurens 5ISS - IR

- Diverse academic backgrounds → all aspects of the project
- Multi-cultural team

Water temperature and flow sensors send data; The solution: an awareness tool; Gateway receives data from sensors; Data is stored in a database on the cloud; Web interface to visualise and analyze the data; Real-time knowledge of consumption

# I. Overview II. The technical requirements

# III. The IoT architecture

### A. The overall architecture B. The Device layer C. The Network layer D. The Application layer

# IV. Project Management V. Conclusion

# The overall architecture


The Device layer; General Architecture; Grove Temperature sensor; YSF 201 Flow sensor; ESP8266 circuit board

# The Device layer

# Hardware Requirements

ESP8266 or ESP32?

ESP32 | ESP8266

Number of cores | 2 | 1
Wi-Fi | Yes | Yes
Bluetooth | Yes | No
Supply needed in Run mode | 110 mA | 80 mA
Supply needed in Sleep mode | 50 mA | 20 mA
Energy consumption per min (I/P=UI/E=PI) | 110mA/0.05Watts/33 Joules | 80mA/0,04 Watts/24 Joules

Energy Management integrated | Yes | No

# The Device layer

# Software Implementation

configuration; Acquiring the Data; Encapsulate into a; “Datas” : [; TEMP; FLOW; DATA

WiFi and Id

Stack data objects in
a JSON array

JSON Object: data

“id” : ”Esp Id”,

# The Network layer

MQTT Packet Payload; "id": "Jamskg",; "Datas": [{; "temp":30.71037,; "debit": 0; "temp":30.53858,; "debit": 56; "debit": 744

BROKER; API; Collected data by the device; Sensor_Data; send_id send_path; store_Sensor_data; The Application layer; Collecting and storing data; Indexing data to identify a device

# The Application layer

# Database requirements


SQL or NoSQL?

SQL | NoSQL

Model | Relational database system | Non-relational database system
Data storage | Tables (rows and columns) | Documents, column stores, graphs, key-value pairs

Schema | Fixed, very hard to modify | Schema-free database, easy to modify

Data structure | Structured data | Semi-structured or unstructured data

New fields | Adding new fields in the table may require altering the schema | New fields can be added with much more ease

WEB INTERFACE; API; Collected data by the device; Indexing data to identify a device get_data; get_data; The Application layer; Retrieving data

# The Application Layer

# Web interface admin (ILYA)


Select and retrieve data from a specific hotel room:

Generate a new id, add a device, update a device’s id:

# The Application Layer

# Web interface client


Select and retrieve data from a specific hotel room:

Sign in or sign up:

# The Application Layer

# Data visualizations


# I. Overview II. The IoT architecture

# III. The solution packaging

### A. The package B. From POC to industrialization

# IV. Project Management V. Conclusion

# The package


- Secure SSH
- GIT
- PYTHON
- Nodejs +
NPM =
NODE-RED
- MongoDB

From POC to industrialization...


POC | Deployment
VM | Containers
Better isolation of data | Easier to configure
Turnkey solution | Fast to deploy
User-friendly | Adaptability/scalability on demand
Needs a hypervisor (VirtualBox, VmWare) | Fast recovery after failure

# I. Overview II. The IoT architecture III. The solution packaging

# IV. Project Management

# V. Conclusion

# Project Management


### - Team meeting: 1 every week - Ilya meeting: 1 every 2 weeks

### - Agile method - Sprints: 3 weeks each - Trello: task management app

# I. Overview II. The IoT architecture III. The solution packaging IV. Project Management

# V. Conclusion

### A. Future improvements B. Summary

# Future improvements


# - Minimize the size of the POC

# - Develop more efficient energy management

# Summary

Requirement | State

### - A functioning POC

### - Database management

### - Data analysis on dashboards

### - Source code comments

### - Documentation

### - Preparation for industrialization

### - Team management


January 23, 2020

## Save Water and Energy

## Consumption Awareness Tool

# The Device layer

# Sensors Specifications


Grove Temperature sensor | YSF 201 Flow sensor
- Thermistor ● Range: -40 - 125 °C ● Accuracy: ±1.5ºC | ● Hall effect Sensor ● Fits well with Arduino ● Low Price

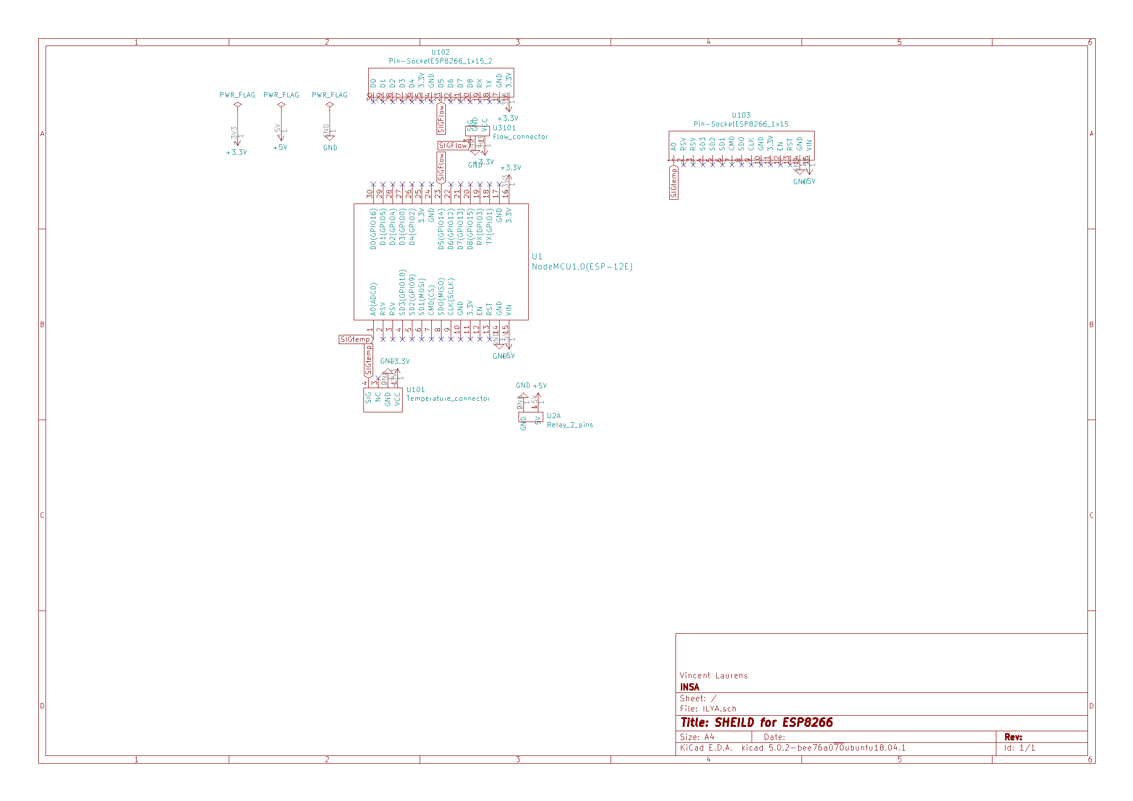
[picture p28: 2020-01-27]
Minimization/PCB/images/KicadILYA.png

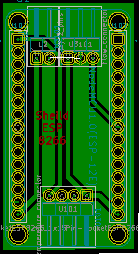
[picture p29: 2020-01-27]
Minimization/PCB/images/plan-de-masse.png

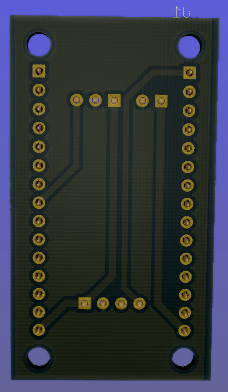
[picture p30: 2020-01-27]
Minimization/PCB/images/3dback.png

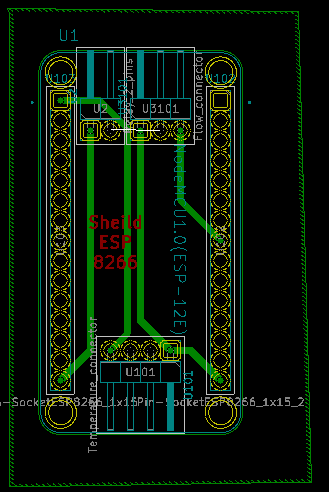
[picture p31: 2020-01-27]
Minimization/PCB/images/PCB_routage.png

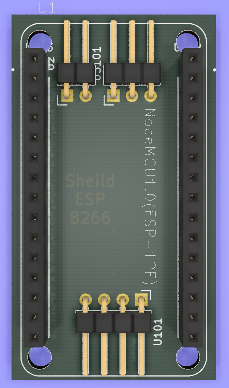
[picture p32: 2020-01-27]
Minimization/PCB/images/3dFront.png

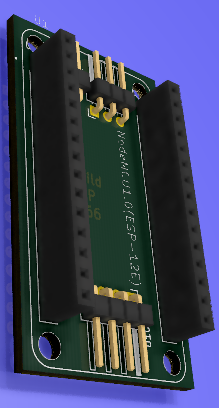
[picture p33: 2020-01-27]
Minimization/PCB/images/3dside.png

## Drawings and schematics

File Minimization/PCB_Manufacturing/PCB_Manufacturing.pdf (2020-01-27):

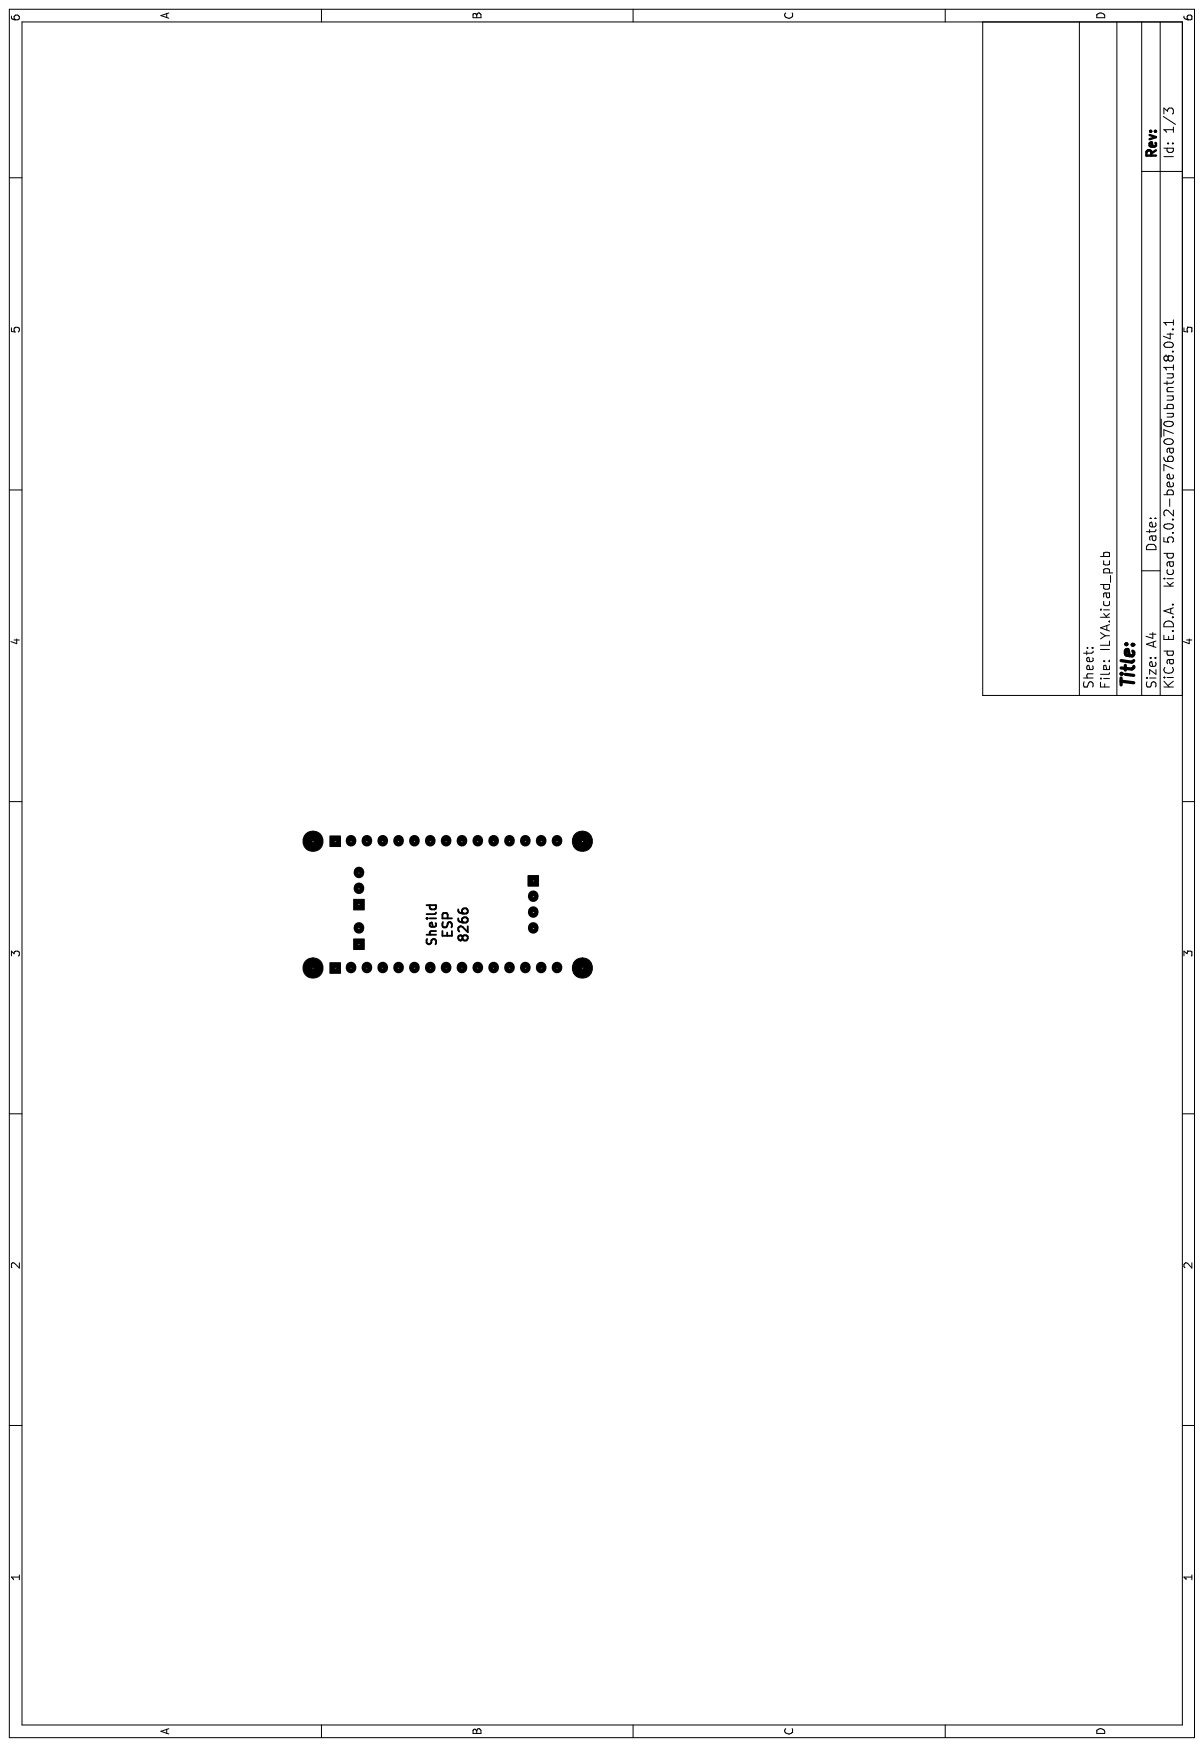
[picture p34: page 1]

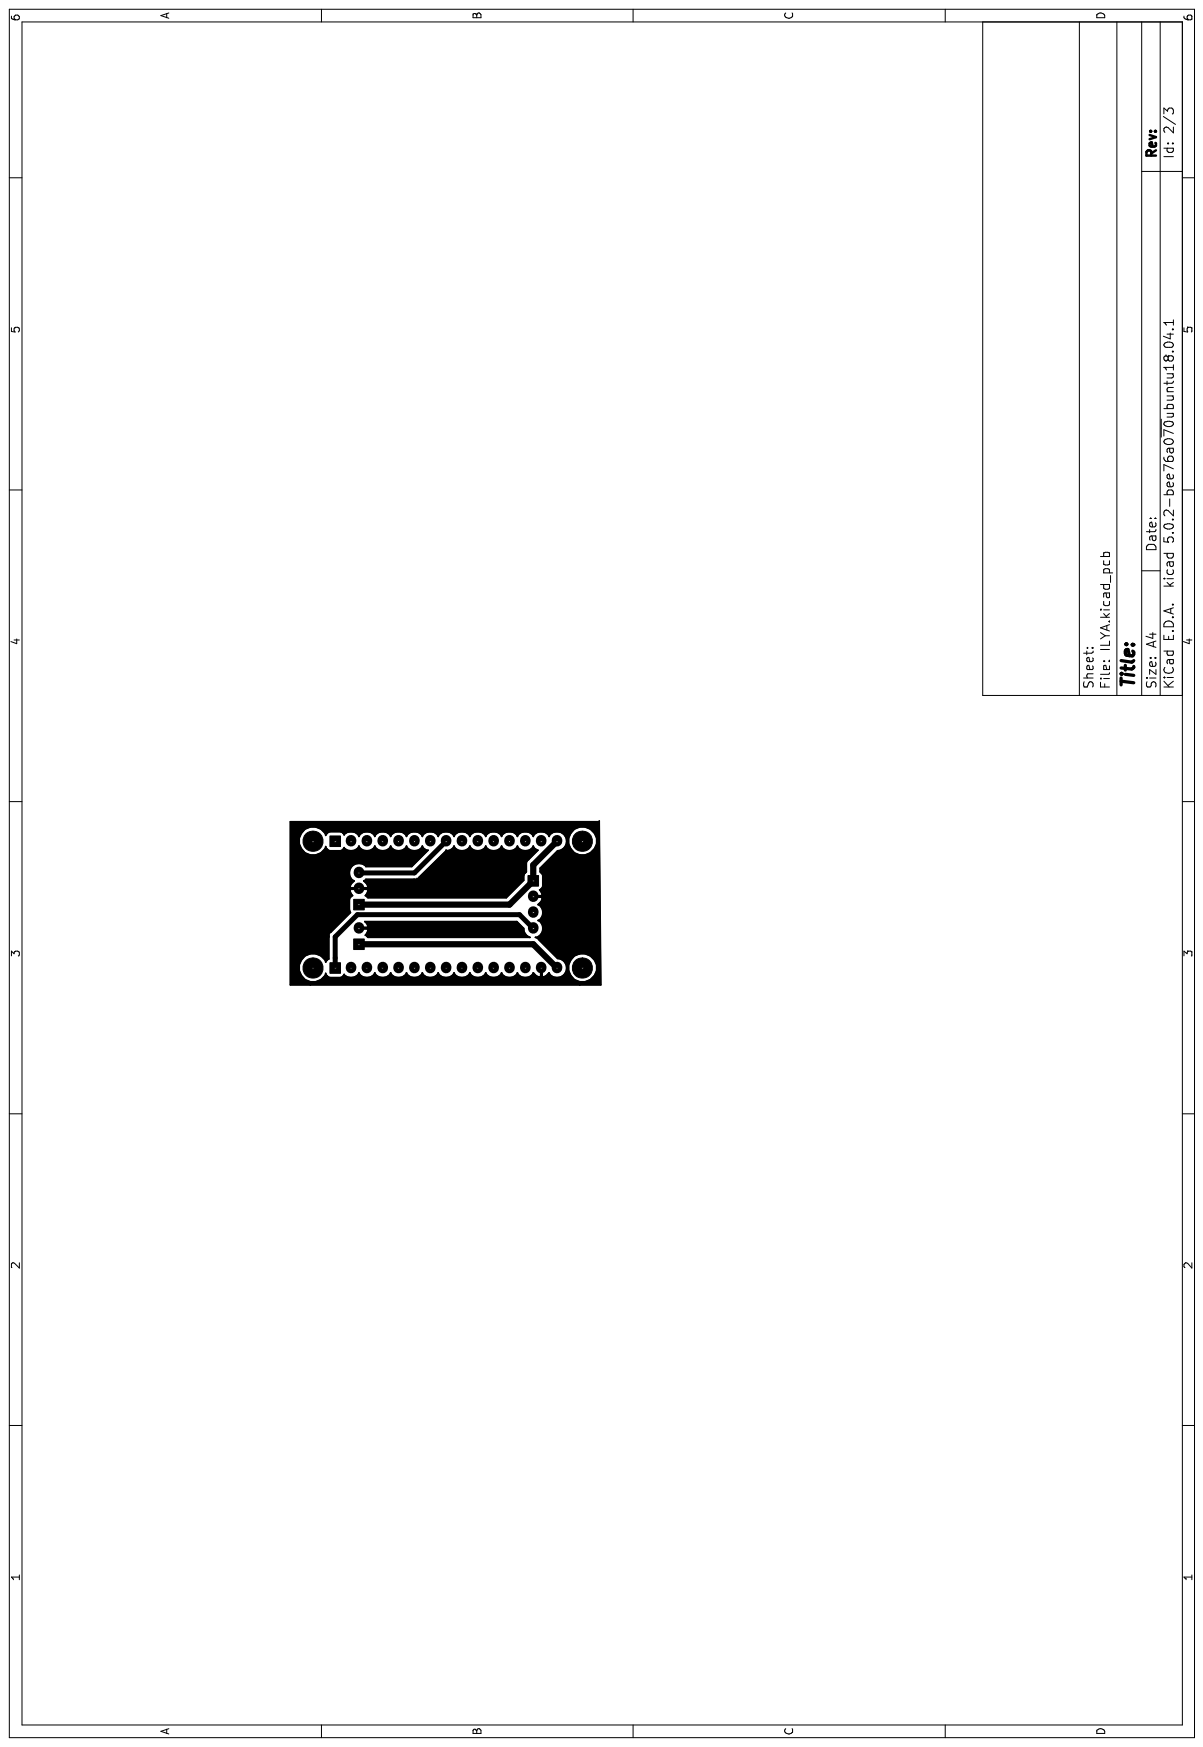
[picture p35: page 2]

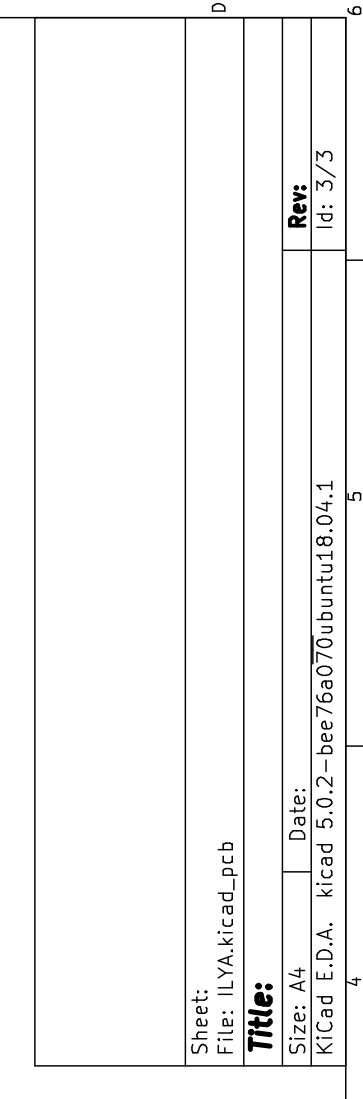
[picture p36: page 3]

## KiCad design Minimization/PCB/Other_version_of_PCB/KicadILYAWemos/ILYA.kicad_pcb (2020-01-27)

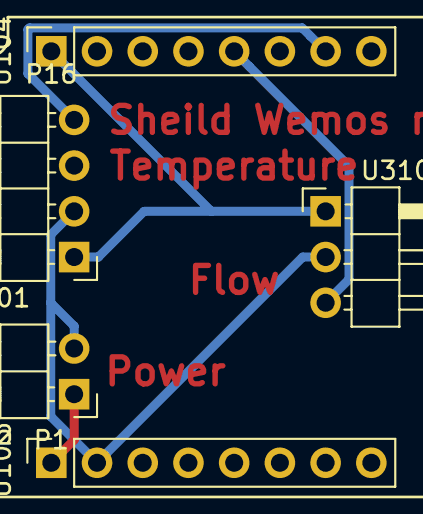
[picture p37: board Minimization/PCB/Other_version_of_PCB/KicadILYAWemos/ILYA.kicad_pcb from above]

Board: 2 copper layers, 6 parts (0 on the bottom side), 5 nets.

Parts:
U2: Relay_2_pins; PinHeader_1x02_P2.54mm_Horizontal
U101: Temperature_connector; PinHeader_1x04_P2.54mm_Horizontal
U102: WeMos_mini; wemos-d1-mini-withoutpin
U103: Pin_socket_1x8; PinSocket_1x08_P2.54mm_Vertical
U104: Pin-socket2_1x08; PinSocket_1x08_P2.54mm_Vertical2
U3101: Flow_connector; PinHeader_1x03_P2.54mm_Horizontal

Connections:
+3V3: U101.1, U104.16, U3101.1
+5V: U2.1, U103.1
GND: U2.2, U101.2, U103.2, U3101.2
SIGFlow: U104.12, U3101.3
SIGTemp: U101.4, U104.10

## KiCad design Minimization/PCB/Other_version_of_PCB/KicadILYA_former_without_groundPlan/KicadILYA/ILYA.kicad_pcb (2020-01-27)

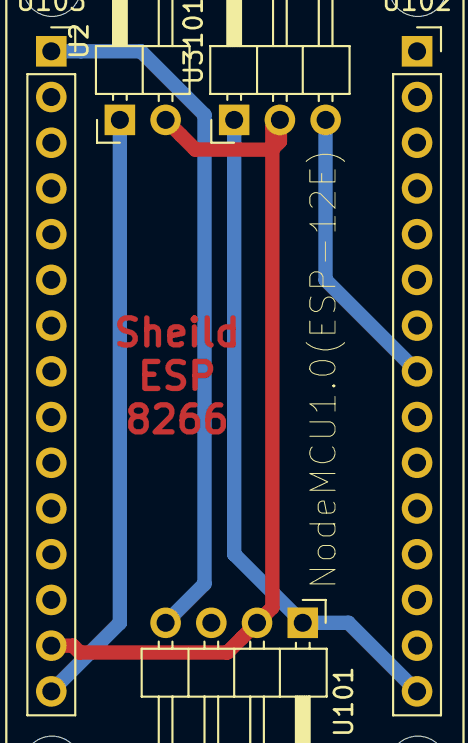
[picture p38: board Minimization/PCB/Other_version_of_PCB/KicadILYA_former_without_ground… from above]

Board: 2 copper layers, 6 parts (0 on the bottom side), 5 nets.

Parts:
U1: NodeMCU1.0(ESP-12E); SEEED_113990105_withoutPin
U2: Relay_2_pins; PinHeader_1x02_P2.54mm_Horizontal
U101: Temperature_connector; PinHeader_1x04_P2.54mm_Horizontal
U102: Pin-SocketESP8266_1x15_2; PinSocket_1x15_P2.54mm_Vertical2
U103: Pin-SocketESP8266_1x15; PinSocket_1x15_P2.54mm_Vertical
U3101: Flow_connector; PinHeader_1x03_P2.54mm_Horizontal

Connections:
+3V3: U101.1, U102.16, U3101.1
+5V: U2.1, U103.15
GND: U2.2, U101.2, U103.14, U3101.2
SIGFlow: U102.23, U3101.3
SIGtemp: U101.4, U103.1

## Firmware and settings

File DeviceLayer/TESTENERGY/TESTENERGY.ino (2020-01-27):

/*
 * Includes
 */
#include <ESP8266WiFi.h>
#include <PubSubClient.h>
#include<ArduinoJson.h>
#include <math.h>
#include <WiFiManager.h>
#include<EEPROM.h>
/*
 * defines
 */
#define WIFI_CONFIG_ADDRESS 10
#define ID_LENGHT 40
#define Nobj 7
//MQTT CONFIG
//Update these with values suitable for your network.
const char* mqtt_server = "maqiatto.com";
#define mqtt_port 1883
#define MQTT_USER "mickaelcommerot1@gmail.com"
#define MQTT_PASSWORD "ilya"
#define MQTT_SERIAL_PUBLISH_CH "mickaelcommerot1@gmail.com/ilya"
#define MQTT_SERIAL_ALERT "mickaelcommerot1@gmail.com/alert"
#define MQTT_SERIAL_RECEIVER_CH "mickaelcommerot1@gmail.com/ilya"

//ESP_ID
String esp_id ;

//Shower Detection variable
bool isShower=false;

//Wifi Manager Config
WiFiClient wifiClient;
WiFiManagerParameter *espid;

//JSON COnfig
  const int capacity = JSON_OBJECT_SIZE(2);
  StaticJsonDocument<capacity> Datadoc;
  StaticJsonDocument<2048> Objectdoc;
  StaticJsonDocument<1024> Datasdoc;
  JsonArray array = Datasdoc.to<JsonArray>();

//TIMER CONFIG
//Time between 2 acquisitions
constexpr unsigned long DatasDelayMs = 10000;
unsigned long DatasPrev = 0;
//Time of a shower (will set isShower to false after 60000ms when the water flow is stopped)
constexpr unsigned long ShowerDelay = 60000;
unsigned long ShowerStop=0;

// Number of discrete sensor acquisition wanted per packet
int DataCounter=0;

PubSubClient client(wifiClient);
//
//Sensors
volatile int flow_frequency; // Measures flow sensor pulses
unsigned int l_hour; // Calculated litres/hour
float temperature;
unsigned long currentTime;
unsigned long cloopTime;
const int B = 4275;               // B value of the thermistor
const int R0 = 100000;            // R0 = 100k
const int pinTempSensor = A0;     // Grove - Temperature Sensor connect to A0
//
//

//EEPROM
/*
 * this function write at a specific eeprom address the Id 
 * @param : add address where to find the Id inside EEPROM
 * @param : data String object that contains the Id
 */
void writeString(char add,String data)
{
  int _size = data.length();
  int i;
  for(i=0;i<_size;i++)
  {
    EEPROM.write(add+i,data[i]);
  }
  EEPROM.write(add+_size,'\0');   //Add termination null character for String Data
  EEPROM.commit();
}

/*
 * This functions returns the Id stored inside the EEPROM at a given address area
 * @param : add address where to find the Id inside EEPROM
 * @return : String that contains the Id at the specific address mentionned
 */
String read_String(char add)
{
  int i;
  char data[100]; //Max 100 Bytes
  int len=0;
  unsigned char k;
  k=EEPROM.read(add);
  while(k != '\0' && len<500)   //Read until null character
  {    
    k=EEPROM.read(add+len);
    data[len]=k;
    len++;
  }
  data[len]='\0';
  return String(data);
}

/*
 * Function used to read data from sensors
 */
void PrintDBTP(){
  int a = analogRead(pinTempSensor);
    float R = 1023.0/a-1.0;
    R = R0*R;
    temperature = 1.0/(log(R/R0)/B+1/298.15)-273.15; // convert to temperature via datasheet
   currentTime = millis();
   // Every second, calculate and print litres/hour
   if(currentTime >= (cloopTime + 1000))
   {
      cloopTime = currentTime; // Updates cloopTime
      // Pulse frequency (Hz) = 7.5Q, Q is flow rate in L/min. Need to be calibrated!
      l_hour = (flow_frequency * 60 / 7.5); // (Pulse frequency x 60 min) / 7.5Q = flowrate in L/hour
      flow_frequency = 0; // Reset Counter
   }
}
/*
 * Interrupt function which occurs when the waterflow sensors is working
 * Increase the flow frequency and set the shower detection to true.
 */
void IRAM_ATTR flow () // Interrupt function
{
   flow_frequency++;
   isShower=true;
   ShowerStop=millis();
}

/*
 * Function used to connect to the mqtt broker
 */
void reconnect() {
  // Loop until we're reconnected
  while (!client.connected()) {
    Serial.print("Attempting MQTT connection...");
    // Create a random client ID
    String clientId = "ESP32Client-";
    clientId += String(random(0xffff), HEX);
    // Attempt to connect
    if (client.connect(clientId.c_str(), MQTT_USER, MQTT_PASSWORD)) {
      Serial.println("connected");
      //Once connected, publish an announcement...
      client.publish(MQTT_SERIAL_ALERT, "connected");
      // ... and resubscribe
      client.subscribe(MQTT_SERIAL_RECEIVER_CH);
    } else {
      Serial.print("failed, rc=");
      Serial.print(client.state());
      Serial.println(" try again in 5 seconds");
      // Wait 5 seconds before retrying
      delay(5000);
    }
  }
}

/*
 * Listner when a message is send to a broker , print the message.
 */
void callback(char* topic, byte *payload, unsigned int length) {
  Serial.println("-------new message from broker-----");
  Serial.print("channel:");
  Serial.println(topic);
  Serial.print("data:");
  Serial.write(payload, length);
  Serial.println();
}

void setup() {
  Serial.begin(9600);
  EEPROM.begin(sizeof(esp_id) + WIFI_CONFIG_ADDRESS);
  esp_id=read_String(WIFI_CONFIG_ADDRESS);
  WiFiManager wifiManager;
  Serial.println("ESP ID after allocating");
  Serial.println(esp_id.c_str());
  espid=new WiFiManagerParameter("EspId", "Esp Id :", esp_id.c_str(), ID_LENGHT);
  wifiManager.addParameter(espid);
  wifiManager.autoConnect("AutoConnectAP"); 
  Serial.println("EEPROM BEFORE ADDING :");
  Serial.println(read_String(WIFI_CONFIG_ADDRESS));
  String idval=espid->getValue();
  if (esp_id!=idval){
  esp_id=idval;
  writeString(WIFI_CONFIG_ADDRESS,esp_id);
  }
   Serial.println("ESP ID after allocating");
  Serial.println(esp_id.c_str());
  Serial.println("EEPROM AFTER ADDING :");
  Serial.println(read_String(WIFI_CONFIG_ADDRESS));
  Serial.println("connected...yeey :)");
  Serial.println("ESP_id setup:)");
  Serial.println(espid->getValue());
  //////
     attachInterrupt(14, flow, RISING); // Setup Interrupt
   sei(); // Enable interrupts
   currentTime = millis();
   cloopTime = currentTime;
   ShowerStop= currentTime;
  //////
  Serial.setTimeout(500);// Set time out for
  client.setServer(mqtt_server, mqtt_port);
  client.setCallback(callback);
  reconnect();
;
}

/*
 * Function usefull to publish serial data
 * we do not use it in the code but it is here just in case
 */
void publishSerialData(char *serialData) {
  if (!client.connected()) {
    reconnect();
  }
  client.publish(MQTT_SERIAL_PUBLISH_CH, serialData);
}

/*
 * Main function of the projet the loop
 */
void loop() {
  client.loop();
  auto now=millis();
  auto calcc=now-ShowerStop;
  if(calcc>ShowerDelay){
  isShower=false;
  }
  if(now-DatasPrev>DatasDelayMs)
  {
    if(DataCounter<Nobj){
      DatasPrev=now;
      PrintDBTP();
      Datadoc.clear();
      Datadoc["temp"] = temperature;
      Datadoc["debit"] = l_hour;  
      String izi;
      serializeJson(Datadoc,izi);
      Serial.println("Datadoc");
      Serial.println(izi);
      array.add(Datadoc);
      DataCounter++;
       Serial.println("DataCounter");
      Serial.println(DataCounter);
    }else{
      DataCounter=0;    
      String Objectrep;
      String Arrayrep;
      serializeJson(array,Arrayrep); 
       Serial.println("Arrayrep");
      Serial.println(Arrayrep.c_str()); 
      Objectdoc["id"]=espid->getValue();
      Objectdoc["Datas"]=array;
      serializeJson(Objectdoc,Objectrep);  
      Serial.println("Objectrep");
      Serial.println(Objectrep.c_str());
      Serial.println("Publishing on :");
      Serial.println(MQTT_SERIAL_PUBLISH_CH);
      client.publish(MQTT_SERIAL_PUBLISH_CH, Objectrep.c_str()); 
      array=Datasdoc.to<JsonArray>();
      Objectdoc.clear();
    }   
  }
}

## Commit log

2019-11-19 add ESP32 communication with broker mqtt
    [sketch_nov19b.ino]
2019-11-20 Node-Red MongoDB with dashbaords
    Stiil to check data parsing before printing on dashboards
2019-12-19 PCB NODEMCU + PCB WEMOS
    [ILYA.kicad_pcb, ILYA.sch]
2019-12-19 Routage Bon mais connexion pins?
    [ILYA.kicad_pcb, ILYA.sch]
2019-12-19 PCB Wemos
    [ILYA.kicad_pcb, ILYA.sch]
2019-12-20 Wemos routage bon mais pin socket error pad near to pad
    [ILYA.kicad_pcb]
2019-12-20 Wemos pcb good
    [ILYA.kicad_pcb, ILYA.sch]
2019-12-20 Sheild esp8266 good
    [ILYA.kicad_pcb, ILYA.sch]
2019-12-21 Seild Wemos good
    [ILYA.kicad_pcb, ILYA.sch]
2019-12-28 Video Kicad
2020-01-06 Correction of tracks size
    [ILYA.kicad_pcb, ILYA.sch]
2020-01-13 Adding fusion, mqtt publish do not work
    [TESTFUSION_EEPROM.ino, sketch_nov19b.ino]
2020-01-31 added description for device layer
